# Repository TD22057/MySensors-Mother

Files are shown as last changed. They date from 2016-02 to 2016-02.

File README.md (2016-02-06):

# MySensors Mother/Daughter board system

This repository contains the PCB design files, 3D renderings, and
software libraries to implement the
[MySensors](http:www.mysensors.org) mother/daughter board system
[described in this
thread](http://forum.mysensors.org/topic/2480/mother-daughter-board-system).

It's a mother/daughter board design using an RFM69 radio (though it
would be easy to change it to an NRF). I have about 10 sensors I need
to make and they're all similar, but not quite the same. This system
allows be to mix and match what I need for each application. It's
designed to be AC powered and uses a single case (see below) for all
of them (~$3/apiece for 10).

The main board has the basic components and supports two daughter
boards (roughly 25mm x 35mm) which plug into the side so the whole
assembly is basically flat (leaving more room in the case for the
switches, connectors, and LED's). An additional third daughter board
can be used for small boards mounted perpendicular to the main boards
(the sensor board below does that) or mounting over the top of the
arduino.

The main board contains:

- 3.3V Arduino Pro Mini
- RFM69 radio
   - side mount for external dipole antenna
   - interior mount with enough space for a helical antenna mounted
     parallel or perpendicular to the board
- 5V->3.3V power supply
- digital signing chip
- flash memory chip
- input and output shift registers
- headers for a switch, LED, and piezo buzzer
- header for SPI (MISO, MOSI, SCK) pins
- 2 side mounted daughter board headers with inputs and outputs from
  the shift registers
- 1 top mounted daughter board header with pins from the mini including
  D3 (IRQ), D5 and D6 (PWM), A3, A4 (SDA), and A5 (SCL)
- all components are top mounted for easier soldering and a bigger
  ground plane for better antenna performance

# Boards

Each daughter board header has 5V, 3.3V, ground, 3 input pins, and 3
output pins.  I've designed seven different daughter boards so far.   

- Valve/motor control board. I'm using this for articulated water
  valves for controlling leaks at the water heater, washing machine,
  etc.  It contains a L9110 motor controller, LED, and valve
  open/closed sensors.
- AC relay board. I'm using this to control simple AC load switching
  (in my case, a recirculation pump).  The board contains an
  opto-isolated AC relay with NO and NC terminals, 1 LED, and 2 sensor
  inputs with pull down resistors.
- DC relay board. I'm using this to control simple DC load switching
  (in my case, a triggering a garage door).  The board contains an
  opto-isolated DC relay with NO and NC terminals, 2 LED's, and 3 sensor
  inputs with pull down resistors.
- Protected input board. I'm using this to trigger when external
  security cameras and motion sensors trip (they both operate on 12V
  signals).  The board contains 3 opto-isolator circuits for
  triggering on 12V lines.
- Parking/RGB sensor board.  This board contains pins for an
  ultrasonic distance sensor and an RGB (neopixel) ring.  It includes
  5V/3.3V level shifting for the distance sensor.  This board must be
  connected to the 3'rd slot which interfaces directly with the
  Arduino pins because of the neopixel timing requirements.
- Sensor board.  3 sensor inputs with pull down resistors and 3 LED
  outputs with 1K resistors.  This is designed primarily for water
  leak detectors.  The rope leak sensor I'm using works better w/ 5V
  input and analog output so sensors can be fed with 5V or 3.3V and
  when connected in the 3'rd slot, they will output to the Arduino's
  analog pins.
- I2C board.  This is simple small board that adds multiple I2C pins.

Here's an image of the assembled boards:

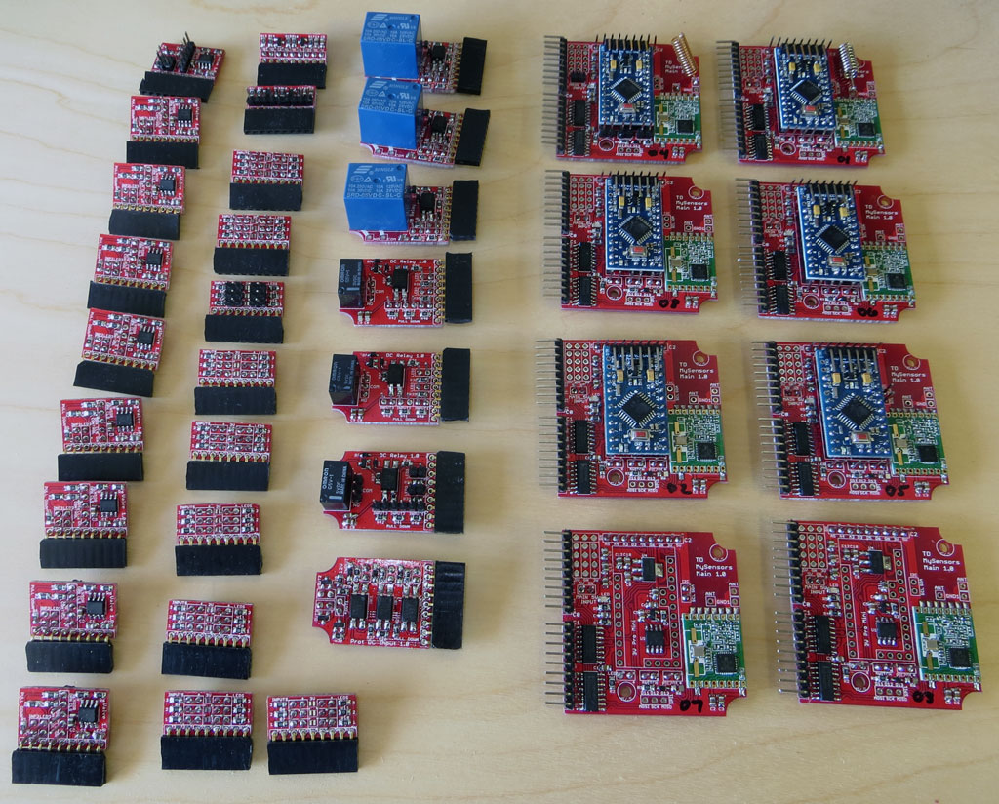
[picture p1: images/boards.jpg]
Boards


# Ordering

The boards file contains the individual board designs (done in Eagle)
as well as panelized versions.  A single 10cm x 10cm panel contains 2
main boards, 1 each of the AC relay, DC relay, protected input,
parking board, and I2C board; 2 valve boards; and 3 sensor boards.  

# Project Case

The boards are designed to fit inside a specific case (size and
mounting holes) which can be [found
here](http://www.aliexpress.com/item/Wholesale-electrical-junction-box-10pcs-105-65-40mm-plastic-instrument-box-plastic-box-electronic-project-box/1986580384.html).
There are many options for ordering this case on AliExpress (various
quantities and vendors).  Searching for ["105\*65\*40mm"](http://www.aliexpress.com/af/105*65*40mm.html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) will
generally show them all.

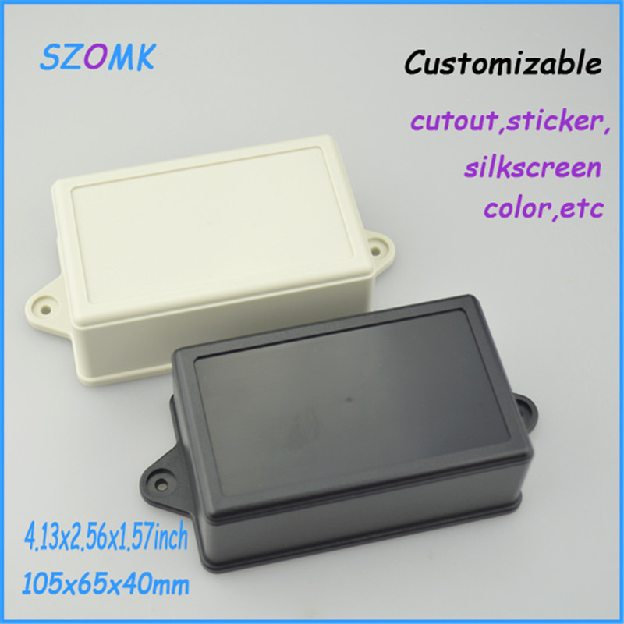
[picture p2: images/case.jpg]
Case


# Software

The lib directory contains a class for each board.  Each child board
class is constructed by passing it a structure from the main board
class which defines which slot it's plugged in to.  The boards (mother
and children) all contain elements for manipulating their components
(LED's, relays, sensors, etc) which abstract away the method by which
their connected (call sensor.led[0].on() to turn on the 0'th LED of a
sensor board) which makes writing the final sketches which use the
boards very easy.

The software does depend on my [arduino-core library
classes](https://github.com/TD22057/TD-Arduino-Core).

# Licenses

All the software in this repository is covered by the GPL-V3 license
(see [LICENSE-software](LICENSE-software)).

All the hardare in this repository is covered by the CERN Open
Hardware Licence v1.2 (see [LICENSE-hardware](LICENSE-hardware)).

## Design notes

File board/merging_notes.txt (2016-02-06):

To created merged board:

Use eagle-brd-merge python script (https://github.com/p12tic/eagle-brd-merge)
Command:
merge.py merge.brd Mother\ v1.0\ -\ panel.brd Child\ v1.0\ -\ panel1.brd --offx .83375mm --offy 50mm

moves child board up 50mm and right a small amount to line up w/ main board cutouts.

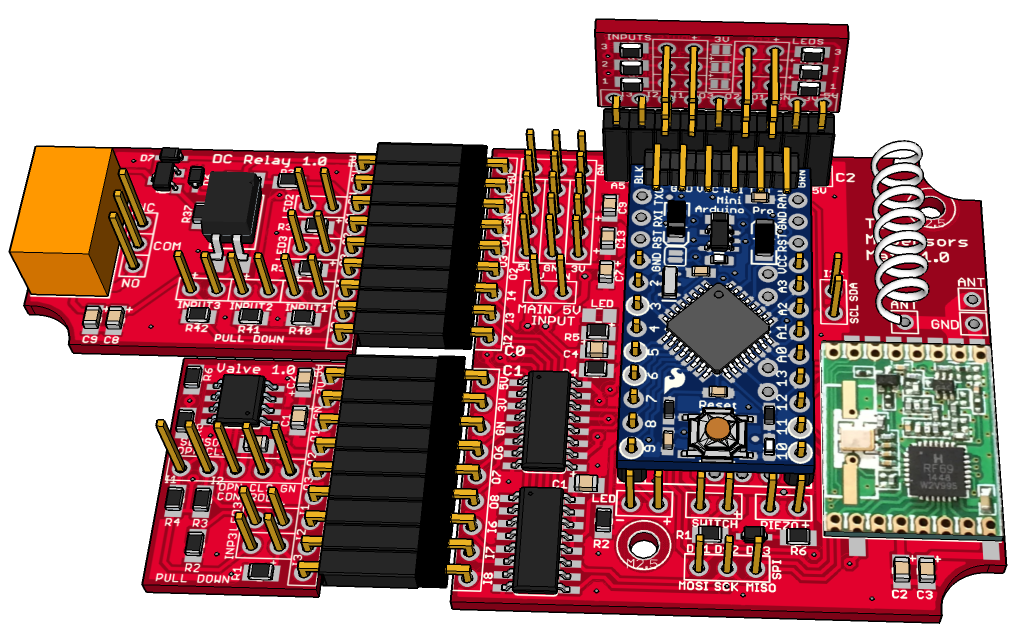
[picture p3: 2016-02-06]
images/main.png

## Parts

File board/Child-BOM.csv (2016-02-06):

Part | Value | Device | Package | Description | Link
C1 | 0.1uF | Capacitor X7R 50V | 805 |  | http://www.aliexpress.com/item/SMD-0805-0-1UF-50V-capacitor-100NF-104K-X7R-10-100pcs/32330657462.html
C2 | 10uF | Capacitor X7R 50V | 805 |  | http://www.aliexpress.com/item/Free-shipping-0805-10UF-50V-106K-10-X7R-100pcs/32333829597.html
C3 | 0.1uF | Capacitor X7R 50V | 805 |  | http://www.aliexpress.com/item/SMD-0805-0-1UF-50V-capacitor-100NF-104K-X7R-10-100pcs/32330657462.html
C4 | 10uF | Capacitor X7R 50V | 805 |  | http://www.aliexpress.com/item/Free-shipping-0805-10UF-50V-106K-10-X7R-100pcs/32333829597.html
C5 | 0.1uF | Capacitor X7R 50V | 805 |  | http://www.aliexpress.com/item/SMD-0805-0-1UF-50V-capacitor-100NF-104K-X7R-10-100pcs/32330657462.html
C6 | 10uF | Capacitor X7R 50V | 805 |  | http://www.aliexpress.com/item/Free-shipping-0805-10UF-50V-106K-10-X7R-100pcs/32333829597.html
C7 | 0.1uF | Capacitor X7R 50V | 805 |  | http://www.aliexpress.com/item/SMD-0805-0-1UF-50V-capacitor-100NF-104K-X7R-10-100pcs/32330657462.html
C8 | 10uF | Capacitor X7R 50V | 805 |  | http://www.aliexpress.com/item/Free-shipping-0805-10UF-50V-106K-10-X7R-100pcs/32333829597.html
C9 | 0.1uF | Capacitor X7R 50V | 805 |  | http://www.aliexpress.com/item/SMD-0805-0-1UF-50V-capacitor-100NF-104K-X7R-10-100pcs/32330657462.html
D1 |  | 1N4148 Diode | SOD323 |  | http://www.aliexpress.com/item/Free-shipping-100PCS-1N4148-SMD-IN4148-0805-SOD-323-Switching-Diode/1578916085.html
D2 |  | 1N4148 Diode | SOD323 |  | http://www.aliexpress.com/item/Free-shipping-100PCS-1N4148-SMD-IN4148-0805-SOD-323-Switching-Diode/1578916085.html
D3 |  | 1N4148 Diode | SOD323 |  | http://www.aliexpress.com/item/Free-shipping-100PCS-1N4148-SMD-IN4148-0805-SOD-323-Switching-Diode/1578916085.html
D4 |  | 1N4148 Diode | SOD323 |  | http://www.aliexpress.com/item/Free-shipping-100PCS-1N4148-SMD-IN4148-0805-SOD-323-Switching-Diode/1578916085.html
D5 |  | 1N4148 Diode | SOD323 |  | http://www.aliexpress.com/item/Free-shipping-100PCS-1N4148-SMD-IN4148-0805-SOD-323-Switching-Diode/1578916085.html
D6 |  | 1N4148 Diode | SOD323 |  | http://www.aliexpress.com/item/Free-shipping-100PCS-1N4148-SMD-IN4148-0805-SOD-323-Switching-Diode/1578916085.html
D7 |  | 1N4148 Diode | SOD323 |  | http://www.aliexpress.com/item/Free-shipping-100PCS-1N4148-SMD-IN4148-0805-SOD-323-Switching-Diode/1578916085.html
L1 |  | BSS138 Mosfet | SOT23-3 | Logic Level converter 5V->3.3V | http://www.aliexpress.com/item/100pcs-lot-DIN7985-M2-5-5mm-Stainless-Steel-A2-Pan-Head-Phillips-Cross-recessed-pan-head/940264374.html
L2 |  | BSS138 Mosfet | SOT23-3 | Logic Level converter 5V->3.3V | http://www.aliexpress.com/item/100pcs-lot-DIN7985-M2-5-5mm-Stainless-Steel-A2-Pan-Head-Phillips-Cross-recessed-pan-head/940264374.html
L9110 |  | L9110 motor driver | SO-08 |  | http://www.aliexpress.com/item/10PCS-free-shipping-100-new-original-patch-of-L9110S-full-bridge-driver-motor-drive-chip-new/1692421710.html
OK1 |  | PC817 optocoupler | SO-4 |  | http://www.aliexpress.com/item/Free-shipping-New-original-Everlight-SMD-optocoupler-EL817C-PC817-EL817S-C-SOP-4-guaranteed-authentic/1911433513.html
OK2 |  | PC817 optocoupler | SO-4 |  | http://www.aliexpress.com/item/Free-shipping-New-original-Everlight-SMD-optocoupler-EL817C-PC817-EL817S-C-SOP-4-guaranteed-authentic/1911433513.html
OK3 |  | PC817 optocoupler | SO-4 |  | http://www.aliexpress.com/item/Free-shipping-New-original-Everlight-SMD-optocoupler-EL817C-PC817-EL817S-C-SOP-4-guaranteed-authentic/1911433513.html
PINP1 |  | 2 pin, male pins |  |  | http://www.aliexpress.com/item/10pcs-Connector-2-54mm-40-Pin-Male-Single-Row-silver-Pin-Header-Strip-Brand-New/32417455102.html
PINP2 |  | 2 pin, male pins |  |  | http://www.aliexpress.com/item/10pcs-Connector-2-54mm-40-Pin-Male-Single-Row-silver-Pin-Header-Strip-Brand-New/32417455102.html
PINP3 |  | 2 pin, male pins |  |  | http://www.aliexpress.com/item/10pcs-Connector-2-54mm-40-Pin-Male-Single-Row-silver-Pin-Header-Strip-Brand-New/32417455102.html
PRK_DIST |  | 4 pin, male pins |  |  | http://www.aliexpress.com/item/10pcs-Connector-2-54mm-40-Pin-Male-Single-Row-silver-Pin-Header-Strip-Brand-New/32417455102.html
PRK_LED |  | 3 pin, male pins |  |  | http://www.aliexpress.com/item/10pcs-Connector-2-54mm-40-Pin-Male-Single-Row-silver-Pin-Header-Strip-Brand-New/32417455102.html
PSWITCH |  | 2 pin, male pins |  |  | http://www.aliexpress.com/item/10pcs-Connector-2-54mm-40-Pin-Male-Single-Row-silver-Pin-Header-Strip-Brand-New/32417455102.html
R1 | 10K | Resistor | 805 |  | http://www.aliexpress.com/item/0805-SMD-Resistors-10k-10K-ohm-1-8W-5-0805-SMD-Resistors-0805-Chip-resistor-500pcs/852348196.html
R2 | 1K | Resistor | 805 |  | http://www.aliexpress.com/item/0805-SMD-Resistors-1k-1K-ohm-1-8W-5-0805-SMD-Resistors-0805-Chip-resistor-500pcs/852303271.html
R2_LED |  | 2 pin, male pins |  |  | http://www.aliexpress.com/item/10pcs-Connector-2-54mm-40-Pin-Male-Single-Row-silver-Pin-Header-Strip-Brand-New/32417455102.html
R2_OC1 |  | PC817 optocoupler | SO-4 |  | http://www.aliexpress.com/item/Free-shipping-New-original-Everlight-SMD-optocoupler-EL817C-PC817-EL817S-C-SOP-4-guaranteed-authentic/1911433513.html
R2_RELAY |  | 5V 10A relay |  |  | http://www.aliexpress.com/item/Free-Shipping-10PCS-SRD-5VDC-SL-C-PCB-Type-5V-DC/662939016.html
R2_SW |  | 2 pin, male pins |  |  | http://www.aliexpress.com/item/10pcs-Connector-2-54mm-40-Pin-Male-Single-Row-silver-Pin-Header-Strip-Brand-New/32417455102.html
R2_SW1 |  | 2 pin, male pins |  |  | http://www.aliexpress.com/item/10pcs-Connector-2-54mm-40-Pin-Male-Single-Row-silver-Pin-Header-Strip-Brand-New/32417455102.html
R3 | 10K | Resistor | 805 |  | http://www.aliexpress.com/item/0805-SMD-Resistors-10k-10K-ohm-1-8W-5-0805-SMD-Resistors-0805-Chip-resistor-500pcs/852348196.html
R3_LED |  | 2 pin, male pins |  |  | http://www.aliexpress.com/item/10pcs-Connector-2-54mm-40-Pin-Male-Single-Row-silver-Pin-Header-Strip-Brand-New/32417455102.html
R3_LED1 |  | 2 pin, male pins |  |  | http://www.aliexpress.com/item/10pcs-Connector-2-54mm-40-Pin-Male-Single-Row-silver-Pin-Header-Strip-Brand-New/32417455102.html
R3_OC |  | PC817 optocoupler | SO-4 |  | http://www.aliexpress.com/item/Free-shipping-New-original-Everlight-SMD-optocoupler-EL817C-PC817-EL817S-C-SOP-4-guaranteed-authentic/1911433513.html
R4 | 10K | Resistor | 805 |  | http://www.aliexpress.com/item/0805-SMD-Resistors-10k-10K-ohm-1-8W-5-0805-SMD-Resistors-0805-Chip-resistor-500pcs/852348196.html
R5 | 10K | Resistor | 805 |  | http://www.aliexpress.com/item/0805-SMD-Resistors-10k-10K-ohm-1-8W-5-0805-SMD-Resistors-0805-Chip-resistor-500pcs/852348196.html
R6 | 10K | Resistor | 805 |  | http://www.aliexpress.com/item/0805-SMD-Resistors-10k-10K-ohm-1-8W-5-0805-SMD-Resistors-0805-Chip-resistor-500pcs/852348196.html
R7 | 10K | Resistor | 805 |  | http://www.aliexpress.com/item/0805-SMD-Resistors-10k-10K-ohm-1-8W-5-0805-SMD-Resistors-0805-Chip-resistor-500pcs/852348196.html
R8 | 10K | Resistor | 805 |  | http://www.aliexpress.com/item/0805-SMD-Resistors-10k-10K-ohm-1-8W-5-0805-SMD-Resistors-0805-Chip-resistor-500pcs/852348196.html
R9 | 10K | Resistor | 805 |  | http://www.aliexpress.com/item/0805-SMD-Resistors-10k-10K-ohm-1-8W-5-0805-SMD-Resistors-0805-Chip-resistor-500pcs/852348196.html
R10 | 1K | Resistor | 805 |  | http://www.aliexpress.com/item/0805-SMD-Resistors-1k-1K-ohm-1-8W-5-0805-SMD-Resistors-0805-Chip-resistor-500pcs/852303271.html
R11 | 1K | Resistor | 805 |  | http://www.aliexpress.com/item/0805-SMD-Resistors-1k-1K-ohm-1-8W-5-0805-SMD-Resistors-0805-Chip-resistor-500pcs/852303271.html
R12 | 1K | Resistor | 805 |  | http://www.aliexpress.com/item/0805-SMD-Resistors-1k-1K-ohm-1-8W-5-0805-SMD-Resistors-0805-Chip-resistor-500pcs/852303271.html
R13 | 10K | Resistor | 805 |  | http://www.aliexpress.com/item/0805-SMD-Resistors-10k-10K-ohm-1-8W-5-0805-SMD-Resistors-0805-Chip-resistor-500pcs/852348196.html
R14 | 10K | Resistor | 805 |  | http://www.aliexpress.com/item/0805-SMD-Resistors-10k-10K-ohm-1-8W-5-0805-SMD-Resistors-0805-Chip-resistor-500pcs/852348196.html
R15 | 10K | Resistor | 805 |  | http://www.aliexpress.com/item/0805-SMD-Resistors-10k-10K-ohm-1-8W-5-0805-SMD-Resistors-0805-Chip-resistor-500pcs/852348196.html
R16 | 10K | Resistor | 805 |  | http://www.aliexpress.com/item/0805-SMD-Resistors-10k-10K-ohm-1-8W-5-0805-SMD-Resistors-0805-Chip-resistor-500pcs/852348196.html
R17 | 10K | Resistor | 805 |  | http://www.aliexpress.com/item/0805-SMD-Resistors-10k-10K-ohm-1-8W-5-0805-SMD-Resistors-0805-Chip-resistor-500pcs/852348196.html
R18 | 4K7 | Resistor | 805 |  | http://www.aliexpress.com/item/0805-SMD-Resistors-4K7-4-7K-ohm-1-8W-5-0805-SMD-Resistors-0805-Chip-resistor/852419496.html
R19 | 4K7 | Resistor | 805 |  | http://www.aliexpress.com/item/0805-SMD-Resistors-4K7-4-7K-ohm-1-8W-5-0805-SMD-Resistors-0805-Chip-resistor/852419496.html
R20 | 10K | Resistor | 805 |  | http://www.aliexpress.com/item/0805-SMD-Resistors-10k-10K-ohm-1-8W-5-0805-SMD-Resistors-0805-Chip-resistor-500pcs/852348196.html
R21 | 10K | Resistor | 805 |  | http://www.aliexpress.com/item/0805-SMD-Resistors-10k-10K-ohm-1-8W-5-0805-SMD-Resistors-0805-Chip-resistor-500pcs/852348196.html
R22 | 4.7K | Resistor | 805 |  | http://www.aliexpress.com/item/0805-SMD-Resistors-4K7-4-7K-ohm-1-8W-5-0805-SMD-Resistors-0805-Chip-resistor/852419496.html
R23 | 4.7K | Resistor | 805 |  | http://www.aliexpress.com/item/0805-SMD-Resistors-4K7-4-7K-ohm-1-8W-5-0805-SMD-Resistors-0805-Chip-resistor/852419496.html
R24 | 4.7K | Resistor | 805 |  | http://www.aliexpress.com/item/0805-SMD-Resistors-4K7-4-7K-ohm-1-8W-5-0805-SMD-Resistors-0805-Chip-resistor/852419496.html
R25 | 10K | Resistor | 805 |  | http://www.aliexpress.com/item/0805-SMD-Resistors-10k-10K-ohm-1-8W-5-0805-SMD-Resistors-0805-Chip-resistor-500pcs/852348196.html
R26 | 10K | Resistor | 805 |  | http://www.aliexpress.com/item/0805-SMD-Resistors-10k-10K-ohm-1-8W-5-0805-SMD-Resistors-0805-Chip-resistor-500pcs/852348196.html
R27 | 10K | Resistor | 805 |  | http://www.aliexpress.com/item/0805-SMD-Resistors-10k-10K-ohm-1-8W-5-0805-SMD-Resistors-0805-Chip-resistor-500pcs/852348196.html
R28 | 1K | Resistor | 805 |  | http://www.aliexpress.com/item/0805-SMD-Resistors-1k-1K-ohm-1-8W-5-0805-SMD-Resistors-0805-Chip-resistor-500pcs/852303271.html
R29 | 1K | Resistor | 805 |  | http://www.aliexpress.com/item/0805-SMD-Resistors-1k-1K-ohm-1-8W-5-0805-SMD-Resistors-0805-Chip-resistor-500pcs/852303271.html
R30 | 1K | Resistor | 805 |  | http://www.aliexpress.com/item/0805-SMD-Resistors-1k-1K-ohm-1-8W-5-0805-SMD-Resistors-0805-Chip-resistor-500pcs/852303271.html
R31 | 1K | Resistor | 805 |  | http://www.aliexpress.com/item/0805-SMD-Resistors-1k-1K-ohm-1-8W-5-0805-SMD-Resistors-0805-Chip-resistor-500pcs/852303271.html
R32 | 1K | Resistor | 805 |  | http://www.aliexpress.com/item/0805-SMD-Resistors-1k-1K-ohm-1-8W-5-0805-SMD-Resistors-0805-Chip-resistor-500pcs/852303271.html
R33 | 10K | Resistor | 805 |  | http://www.aliexpress.com/item/0805-SMD-Resistors-10k-10K-ohm-1-8W-5-0805-SMD-Resistors-0805-Chip-resistor-500pcs/852348196.html
R34 | 1K | Resistor | 805 |  | http://www.aliexpress.com/item/0805-SMD-Resistors-1k-1K-ohm-1-8W-5-0805-SMD-Resistors-0805-Chip-resistor-500pcs/852303271.html
R35 | 10K | Resistor | 805 |  | http://www.aliexpress.com/item/0805-SMD-Resistors-10k-10K-ohm-1-8W-5-0805-SMD-Resistors-0805-Chip-resistor-500pcs/852348196.html
R36 | 1K | Resistor | 805 |  | http://www.aliexpress.com/item/0805-SMD-Resistors-1k-1K-ohm-1-8W-5-0805-SMD-Resistors-0805-Chip-resistor-500pcs/852303271.html
R37 | 1K | Resistor | 805 |  | http://www.aliexpress.com/item/0805-SMD-Resistors-1k-1K-ohm-1-8W-5-0805-SMD-Resistors-0805-Chip-resistor-500pcs/852303271.html
R38 | 1K | Resistor | 805 |  | http://www.aliexpress.com/item/0805-SMD-Resistors-1k-1K-ohm-1-8W-5-0805-SMD-Resistors-0805-Chip-resistor-500pcs/852303271.html
R39 | 1K | Resistor | 805 |  | http://www.aliexpress.com/item/0805-SMD-Resistors-1k-1K-ohm-1-8W-5-0805-SMD-Resistors-0805-Chip-resistor-500pcs/852303271.html
R40 | 10K | Resistor | 805 |  | http://www.aliexpress.com/item/0805-SMD-Resistors-10k-10K-ohm-1-8W-5-0805-SMD-Resistors-0805-Chip-resistor-500pcs/852348196.html
R41 | 10K | Resistor | 805 |  | http://www.aliexpress.com/item/0805-SMD-Resistors-10k-10K-ohm-1-8W-5-0805-SMD-Resistors-0805-Chip-resistor-500pcs/852348196.html
R42 | 10K | Resistor | 805 |  | http://www.aliexpress.com/item/0805-SMD-Resistors-10k-10K-ohm-1-8W-5-0805-SMD-Resistors-0805-Chip-resistor-500pcs/852348196.html
RELAY4 |  | 2 pin, male pins |  |  | http://www.aliexpress.com/item/10pcs-Connector-2-54mm-40-Pin-Male-Single-Row-silver-Pin-Header-Strip-Brand-New/32417455102.html
RELAY5 |  | 2 pin, male pins |  |  | http://www.aliexpress.com/item/10pcs-Connector-2-54mm-40-Pin-Male-Single-Row-silver-Pin-Header-Strip-Brand-New/32417455102.html
RELAY6 |  | 2 pin, male pins |  |  | http://www.aliexpress.com/item/10pcs-Connector-2-54mm-40-Pin-Male-Single-Row-silver-Pin-Header-Strip-Brand-New/32417455102.html
RINP4 |  | 2 pin, male pins |  |  | http://www.aliexpress.com/item/10pcs-Connector-2-54mm-40-Pin-Male-Single-Row-silver-Pin-Header-Strip-Brand-New/32417455102.html
RINP5 |  | 2 pin, male pins |  |  | http://www.aliexpress.com/item/10pcs-Connector-2-54mm-40-Pin-Male-Single-Row-silver-Pin-Header-Strip-Brand-New/32417455102.html
RINP6 |  | 2 pin, male pins |  |  | http://www.aliexpress.com/item/10pcs-Connector-2-54mm-40-Pin-Male-Single-Row-silver-Pin-Header-Strip-Brand-New/32417455102.html
SENLED1 |  | 2 pin, male pins |  |  | http://www.aliexpress.com/item/10pcs-Connector-2-54mm-40-Pin-Male-Single-Row-silver-Pin-Header-Strip-Brand-New/32417455102.html
SENLED2 |  | 2 pin, male pins |  |  | http://www.aliexpress.com/item/10pcs-Connector-2-54mm-40-Pin-Male-Single-Row-silver-Pin-Header-Strip-Brand-New/32417455102.html
SENLED3 |  | 2 pin, male pins |  |  | http://www.aliexpress.com/item/10pcs-Connector-2-54mm-40-Pin-Male-Single-Row-silver-Pin-Header-Strip-Brand-New/32417455102.html
SENSOR1 |  | 2 pin, male pins |  |  | http://www.aliexpress.com/item/10pcs-Connector-2-54mm-40-Pin-Male-Single-Row-silver-Pin-Header-Strip-Brand-New/32417455102.html
SENSOR2 |  | 2 pin, male pins |  |  | http://www.aliexpress.com/item/10pcs-Connector-2-54mm-40-Pin-Male-Single-Row-silver-Pin-Header-Strip-Brand-New/32417455102.html
SENSOR3 |  | 2 pin, male pins |  |  | http://www.aliexpress.com/item/10pcs-Connector-2-54mm-40-Pin-Male-Single-Row-silver-Pin-Header-Strip-Brand-New/32417455102.html
SENSOR4 |  | 2 pin, male pins |  |  | http://www.aliexpress.com/item/10pcs-Connector-2-54mm-40-Pin-Male-Single-Row-silver-Pin-Header-Strip-Brand-New/32417455102.html
SENSOR5 |  | 2 pin, male pins |  |  | http://www.aliexpress.com/item/10pcs-Connector-2-54mm-40-Pin-Male-Single-Row-silver-Pin-Header-Strip-Brand-New/32417455102.html
SENSOR7 |  | 2 pin, male pins |  |  | http://www.aliexpress.com/item/10pcs-Connector-2-54mm-40-Pin-Male-Single-Row-silver-Pin-Header-Strip-Brand-New/32417455102.html
SENSOR8 |  | 2 pin, male pins |  |  | http://www.aliexpress.com/item/10pcs-Connector-2-54mm-40-Pin-Male-Single-Row-silver-Pin-Header-Strip-Brand-New/32417455102.html
U$1 |  | 9 pin, female, 90 deg header |  |  | http://www.aliexpress.com/item/10pcs-1x40-Pin-2-54mm-Right-Angle-Single-Row-Female-Pin-Header-Connector/32412624930.html
U$2 |  | 9 pin, female, 90 deg header |  |  | http://www.aliexpress.com/item/10pcs-1x40-Pin-2-54mm-Right-Angle-Single-Row-Female-Pin-Header-Connector/32412624930.html
U$3 |  | G5V 5V relay |  |  | http://www.aliexpress.com/item/G5V-1-5V-g5v-1-5-G5V-1-5VDC-5pcs-lot/32380269321.html
U$4 |  | 9 pin, female, 90 deg header |  |  | http://www.aliexpress.com/item/10pcs-1x40-Pin-2-54mm-Right-Angle-Single-Row-Female-Pin-Header-Connector/32412624930.html
U$6 |  | 9 pin, female, 90 deg header |  |  | http://www.aliexpress.com/item/10pcs-1x40-Pin-2-54mm-Right-Angle-Single-Row-Female-Pin-Header-Connector/32412624930.html
U$7 |  | 9 pin, female, 90 deg header |  |  | http://www.aliexpress.com/item/10pcs-1x40-Pin-2-54mm-Right-Angle-Single-Row-Female-Pin-Header-Connector/32412624930.html
U$8 |  | 2N2222 Transistor | SOT23-3 |  | http://www.aliexpress.com/item/MMBT2222A-patch-Transistor-2N2222-SMD-1P-printing-package-SOT23-NPN-KBSM/32469039785.html
U$9 |  | 1 pin, male pins |  |  | http://www.aliexpress.com/item/10pcs-Connector-2-54mm-40-Pin-Male-Single-Row-silver-Pin-Header-Strip-Brand-New/32417455102.html
U$10 |  | 1 pin, male pins |  |  | http://www.aliexpress.com/item/10pcs-Connector-2-54mm-40-Pin-Male-Single-Row-silver-Pin-Header-Strip-Brand-New/32417455102.html
U$11 |  | 1 pin, male pins |  |  | http://www.aliexpress.com/item/10pcs-Connector-2-54mm-40-Pin-Male-Single-Row-silver-Pin-Header-Strip-Brand-New/32417455102.html
U$12 |  | 1 pin, male pins |  |  | http://www.aliexpress.com/item/10pcs-Connector-2-54mm-40-Pin-Male-Single-Row-silver-Pin-Header-Strip-Brand-New/32417455102.html
U$13 |  | 2N2222 Transistor | SOT23-3
U$14 |  | 9 pin, female, 90 deg header |  |  | http://www.aliexpress.com/item/10pcs-1x40-Pin-2-54mm-Right-Angle-Single-Row-Female-Pin-Header-Connector/32412624930.html
U$15 |  | 1 pin, male pins |  |  | http://www.aliexpress.com/item/10pcs-Connector-2-54mm-40-Pin-Male-Single-Row-silver-Pin-Header-Strip-Brand-New/32417455102.html
U$16 |  | 1 pin, male pins |  |  | http://www.aliexpress.com/item/10pcs-Connector-2-54mm-40-Pin-Male-Single-Row-silver-Pin-Header-Strip-Brand-New/32417455102.html
U$17 |  | 1 pin, male pins |  |  | http://www.aliexpress.com/item/10pcs-Connector-2-54mm-40-Pin-Male-Single-Row-silver-Pin-Header-Strip-Brand-New/32417455102.html
U$18 |  | 9 pin, female, 90 deg header |  |  | http://www.aliexpress.com/item/10pcs-1x40-Pin-2-54mm-Right-Angle-Single-Row-Female-Pin-Header-Connector/32412624930.html
U$19 |  | 1 pin, male pins |  |  | http://www.aliexpress.com/item/10pcs-Connector-2-54mm-40-Pin-Male-Single-Row-silver-Pin-Header-Strip-Brand-New/32417455102.html
U$20 |  | 1 pin, male pins |  |  | http://www.aliexpress.com/item/10pcs-Connector-2-54mm-40-Pin-Male-Single-Row-silver-Pin-Header-Strip-Brand-New/32417455102.html
U$21 |  | 1 pin, male pins |  |  | http://www.aliexpress.com/item/10pcs-Connector-2-54mm-40-Pin-Male-Single-Row-silver-Pin-Header-Strip-Brand-New/32417455102.html
U$22 |  | 1 pin, male pins |  |  | http://www.aliexpress.com/item/10pcs-Connector-2-54mm-40-Pin-Male-Single-Row-silver-Pin-Header-Strip-Brand-New/32417455102.html
U$23 |  | 3 pin, male pins |  |  | http://www.aliexpress.com/item/10pcs-Connector-2-54mm-40-Pin-Male-Single-Row-silver-Pin-Header-Strip-Brand-New/32417455102.html
U$24 |  | 3 pin, male pins |  |  | http://www.aliexpress.com/item/10pcs-Connector-2-54mm-40-Pin-Male-Single-Row-silver-Pin-Header-Strip-Brand-New/32417455102.html
U2 |  | 2N2222 Transistor | SOT23-3 |  | http://www.aliexpress.com/item/MMBT2222A-patch-Transistor-2N2222-SMD-1P-printing-package-SOT23-NPN-KBSM/32469039785.html
U5 |  | 2N2222 Transistor | SOT23-3 |  | http://www.aliexpress.com/item/MMBT2222A-patch-Transistor-2N2222-SMD-1P-printing-package-SOT23-NPN-KBSM/32469039785.html
U6 |  | 2N2222 Transistor | SOT23-3 |  | http://www.aliexpress.com/item/MMBT2222A-patch-Transistor-2N2222-SMD-1P-printing-package-SOT23-NPN-KBSM/32469039785.html
VALVE |  | 5 pin, male pins |  |  | http://www.aliexpress.com/item/10pcs-Connector-2-54mm-40-Pin-Male-Single-Row-silver-Pin-Header-Strip-Brand-New/32417455102.html
VLV_LED |  | 2 pin, male pins |  |  | http://www.aliexpress.com/item/10pcs-Connector-2-54mm-40-Pin-Male-Single-Row-silver-Pin-Header-Strip-Brand-New/32417455102.html

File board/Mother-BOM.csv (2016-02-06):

Part | Value | Device | Package | Description | Link
C1 | 0.1uF | Capacitor X7R 50V | 805 |  | http://www.aliexpress.com/item/SMD-0805-0-1UF-50V-capacitor-100NF-104K-X7R-10-100pcs/32330657462.html
C2 | 10uF | Capacitor X7R 50V | 805 |  | http://www.aliexpress.com/item/Free-shipping-0805-10UF-50V-106K-10-X7R-100pcs/32333829597.html
C3 | 0.1uF | Capacitor X7R 50V | 805 |  | http://www.aliexpress.com/item/SMD-0805-0-1UF-50V-capacitor-100NF-104K-X7R-10-100pcs/32330657462.html
C4 | 0.1uF | Capacitor X7R 50V | 805 |  | http://www.aliexpress.com/item/SMD-0805-0-1UF-50V-capacitor-100NF-104K-X7R-10-100pcs/32330657462.html
C5 | 0.1uF | Capacitor X7R 50V | 805 |  | http://www.aliexpress.com/item/SMD-0805-0-1UF-50V-capacitor-100NF-104K-X7R-10-100pcs/32330657462.html
C6 | 0.1uF | Capacitor X7R 50V | 805 |  | http://www.aliexpress.com/item/SMD-0805-0-1UF-50V-capacitor-100NF-104K-X7R-10-100pcs/32330657462.html
C7 | 10uF | Capacitor X7R 50V | 805 |  | http://www.aliexpress.com/item/Free-shipping-0805-10UF-50V-106K-10-X7R-100pcs/32333829597.html
C8 | 0.1uF | Capacitor X7R 50V | 805 |  | http://www.aliexpress.com/item/SMD-0805-0-1UF-50V-capacitor-100NF-104K-X7R-10-100pcs/32330657462.html
C9 | 10uF | Capacitor X7R 50V | 805 |  | http://www.aliexpress.com/item/Free-shipping-0805-10UF-50V-106K-10-X7R-100pcs/32333829597.html
C10 | 0.1uF | Capacitor X7R 50V | 805 |  | http://www.aliexpress.com/item/SMD-0805-0-1UF-50V-capacitor-100NF-104K-X7R-10-100pcs/32330657462.html
C11 | 10uF | Capacitor X7R 50V | 805 |  | http://www.aliexpress.com/item/Free-shipping-0805-10UF-50V-106K-10-X7R-100pcs/32333829597.html
C12 | 10uF | Capacitor X7R 50V | 805 |  | http://www.aliexpress.com/item/Free-shipping-0805-10UF-50V-106K-10-X7R-100pcs/32333829597.html
C13 | 10uF | Capacitor X7R 50V | 805 |  | http://www.aliexpress.com/item/Free-shipping-0805-10UF-50V-106K-10-X7R-100pcs/32333829597.html
D1 |  | 1N4148 Diode | SOD323 |  | http://www.aliexpress.com/item/Free-shipping-100PCS-1N4148-SMD-IN4148-0805-SOD-323-Switching-Diode/1578916085.html
H1 |  | M2.5 mounting hole |  |  | http://www.aliexpress.com/item/100pcs-lot-DIN7985-M2-5-5mm-Stainless-Steel-A2-Pan-Head-Phillips-Cross-recessed-pan-head/940264374.html
H2 |  | M2.5 mounting hole |  |  | http://www.aliexpress.com/item/100pcs-lot-DIN7985-M2-5-5mm-Stainless-Steel-A2-Pan-Head-Phillips-Cross-recessed-pan-head/940264374.html
I2C |  | 2 pin, male pins |  |  | http://www.aliexpress.com/item/10pcs-Connector-2-54mm-40-Pin-Male-Single-Row-silver-Pin-Header-Strip-Brand-New/32417455102.html
IC_IN |  | MM74HC589 | SO16 | Input shift register with SPI support | https://www.digikey.com/product-detail/en/MC74HC589ADG/MC74HC589ADGOS-ND/1480105
IC_OUT |  | 74HC595 | SO16 | Output shift register | http://www.aliexpress.com/item/Free-shipping-50pcs-74HC595D-74HC595-SOP16/910702058.html
J3V1 |  | 4 pin, male pins |  |  | http://www.aliexpress.com/item/10pcs-Connector-2-54mm-40-Pin-Male-Single-Row-silver-Pin-Header-Strip-Brand-New/32417455102.html
J5V |  | 4 pin, male pins |  |  | http://www.aliexpress.com/item/10pcs-Connector-2-54mm-40-Pin-Male-Single-Row-silver-Pin-Header-Strip-Brand-New/32417455102.html
JGN1 |  | 4 pin, male pins |  |  | http://www.aliexpress.com/item/10pcs-Connector-2-54mm-40-Pin-Male-Single-Row-silver-Pin-Header-Strip-Brand-New/32417455102.html
JGN2 |  | 3 pin, male pins |  |  | http://www.aliexpress.com/item/10pcs-Connector-2-54mm-40-Pin-Male-Single-Row-silver-Pin-Header-Strip-Brand-New/32417455102.html
JINP |  | 2 pin, male pins |  |  | http://www.aliexpress.com/item/10pcs-Connector-2-54mm-40-Pin-Male-Single-Row-silver-Pin-Header-Strip-Brand-New/32417455102.html
LED |  | 2 pin, male pins |  |  | http://www.aliexpress.com/item/10pcs-Connector-2-54mm-40-Pin-Male-Single-Row-silver-Pin-Header-Strip-Brand-New/32417455102.html
LED_SYS |  | SMD LED | 805 |  | http://www.aliexpress.com/item/Free-Shipping-100PCS-0805-Ultra-Bright-SMD-R-G-B-W-Y-LEDs-yellow-blue-White/1596620234.html
PIEZO |  | 2 pin, male pins |  |  | http://www.aliexpress.com/item/10pcs-Connector-2-54mm-40-Pin-Male-Single-Row-silver-Pin-Header-Strip-Brand-New/32417455102.html
R1 | 10K | Resistor | 805 |  | http://www.aliexpress.com/item/0805-SMD-Resistors-10k-10K-ohm-1-8W-5-0805-SMD-Resistors-0805-Chip-resistor-500pcs/852348196.html
R2 | 1K | Resistor | 805 |  | http://www.aliexpress.com/item/0805-SMD-Resistors-1k-1K-ohm-1-8W-5-0805-SMD-Resistors-0805-Chip-resistor-500pcs/852303271.html
R3 | 4.7K | Resistor | 805 |  | http://www.aliexpress.com/item/0805-SMD-Resistors-4K7-4-7K-ohm-1-8W-5-0805-SMD-Resistors-0805-Chip-resistor/852419496.html
R4 | 10K | Resistor | 805 |  | http://www.aliexpress.com/item/0805-SMD-Resistors-10k-10K-ohm-1-8W-5-0805-SMD-Resistors-0805-Chip-resistor-500pcs/852348196.html
R5 | 1K | Resistor | 805 |  | http://www.aliexpress.com/item/0805-SMD-Resistors-1k-1K-ohm-1-8W-5-0805-SMD-Resistors-0805-Chip-resistor-500pcs/852303271.html
R6 | 47 | Resistor | 805 |  | http://www.aliexpress.com/store/product/0805-SMD-Resistors-47R-47-ohm-1-8W-5-0805-SMD-Resistors-0805-Chip-resistor-500pcs/821060_851435603.html
SPI |  | 3 pin, male pins |  |  | http://www.aliexpress.com/item/10pcs-Connector-2-54mm-40-Pin-Male-Single-Row-silver-Pin-Header-Strip-Brand-New/32417455102.html
SWITCH |  | 2 pin, male pins |  |  | http://www.aliexpress.com/item/10pcs-Connector-2-54mm-40-Pin-Male-Single-Row-silver-Pin-Header-Strip-Brand-New/32417455102.html
U$1 |  | 9 pin, male 90 deg pins |  |  | http://www.aliexpress.com/item/10PCS-1x40-Pin-2-54mm-Right-Angle-Single-Row-Male-Pin-Header-Connector/32403777838.html
U$3 |  | 9 pin, male 90 deg pins |  |  | http://www.aliexpress.com/item/10PCS-1x40-Pin-2-54mm-Right-Angle-Single-Row-Male-Pin-Header-Connector/32403777838.html
U$4 |  | 9 pin, male pins |  |  | http://www.aliexpress.com/item/10pcs-Connector-2-54mm-40-Pin-Male-Single-Row-silver-Pin-Header-Strip-Brand-New/32417455102.html
U1 |  | EEPROM memory | SO-08 | 512K flash memory | https://www.digikey.com/product-detail/en/AT25DF512C-SSHN-B/1265-1179-5-ND/4901487
U2 |  | ATSHA204A | SOT23-3 | Crypto chip | https://www.digikey.com/product-detail/en/ATSHA204A-STUCZ-T/ATSHA204A-STUCZ-TCT-ND/4814557
U3 |  | 3.3V Arduino Pro Mini Clone | PRO_MINI_CLONE_NO_PROG | ABK Pro-Mini Arduino Clone | http://www.aliexpress.com/item/Free-Shipping-1pcs-pro-mini-atmega328-Pro-Mini-328-Mini-ATMEGA328-3-3V-8MHz-for-Arduino/32340942669.html
U4 |  | AMS1117 3.3V | SOT223 |  | http://www.aliexpress.com/item/50pcs-AMS1117-3-3-AMS1117-LM1117-1117-3-3V-1A-Voltage-Regulator/32347685609.html
U5 |  | RFM69W radio |  |  | http://www.ebay.com/itm/181170695434?_trksid=p2057872.m2749.l2649&ssPageName=STRK%3AMEBIDX%3AIT
Miscellaneous Items
Case |  |  |  |  | http://www.aliexpress.com/item/Wholesale-electrical-junction-box-10pcs-105-65-40mm-plastic-instrument-box-plastic-box-electronic-project-box/1986580384.html
Antenna |  |  |  |  | http://www.aliexpress.com/item/20pcs-lot-helical-antenna-SW915-TH12-915MHz-12-5mm-Copper-spring-antenna-for-wireless-RF-module/2043535002.html
Piezo |  | 3V buzzer |  |  | http://www.ebay.com/itm/181502256974?_trksid=p2057872.m2749.l2649&ssPageName=STRK%3AMEBIDX%3AIT

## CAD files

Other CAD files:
sketchup/input.skp
sketchup/relay_ac.skp
sketchup/relay_dc.skp
sketchup/sensor.skp
sketchup/valve.skp

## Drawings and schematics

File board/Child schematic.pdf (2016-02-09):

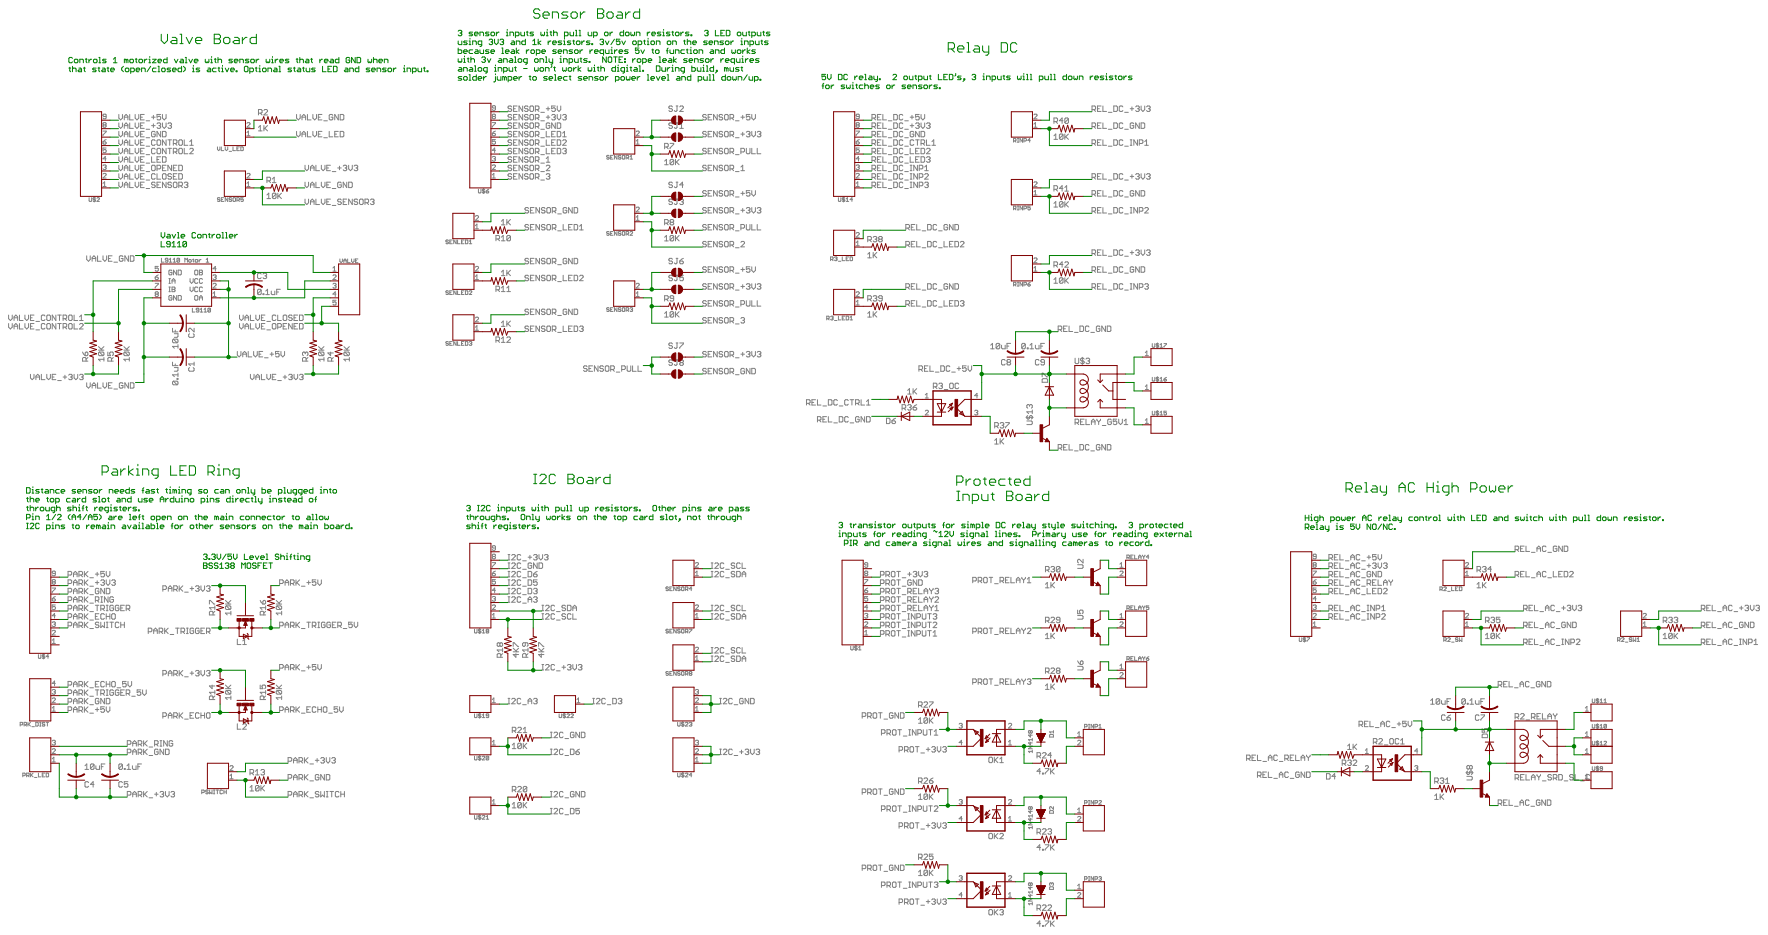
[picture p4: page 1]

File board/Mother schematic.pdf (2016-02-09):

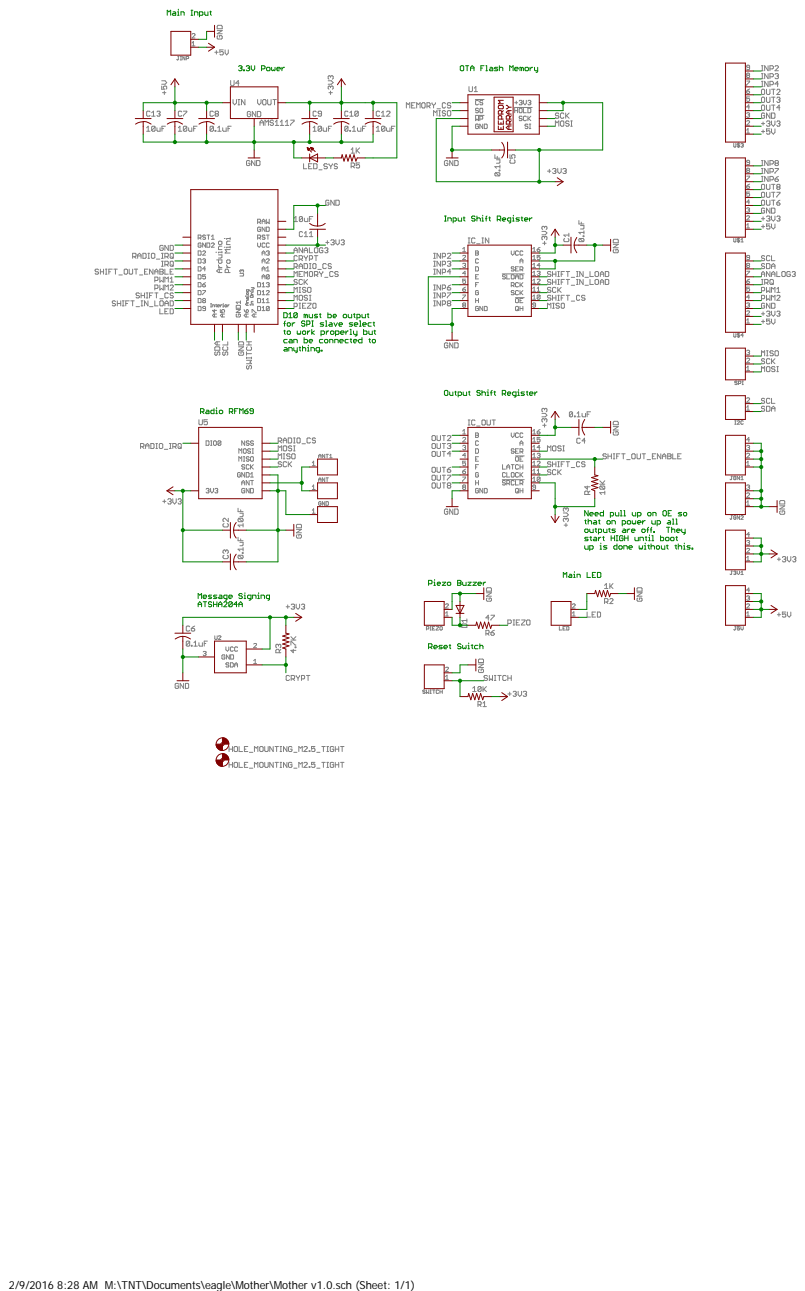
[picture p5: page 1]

2/9/2016 8:28 AM M:\TNT\Documents\eagle\Mother\Mother v1.0.sch (Sheet: 1/1)

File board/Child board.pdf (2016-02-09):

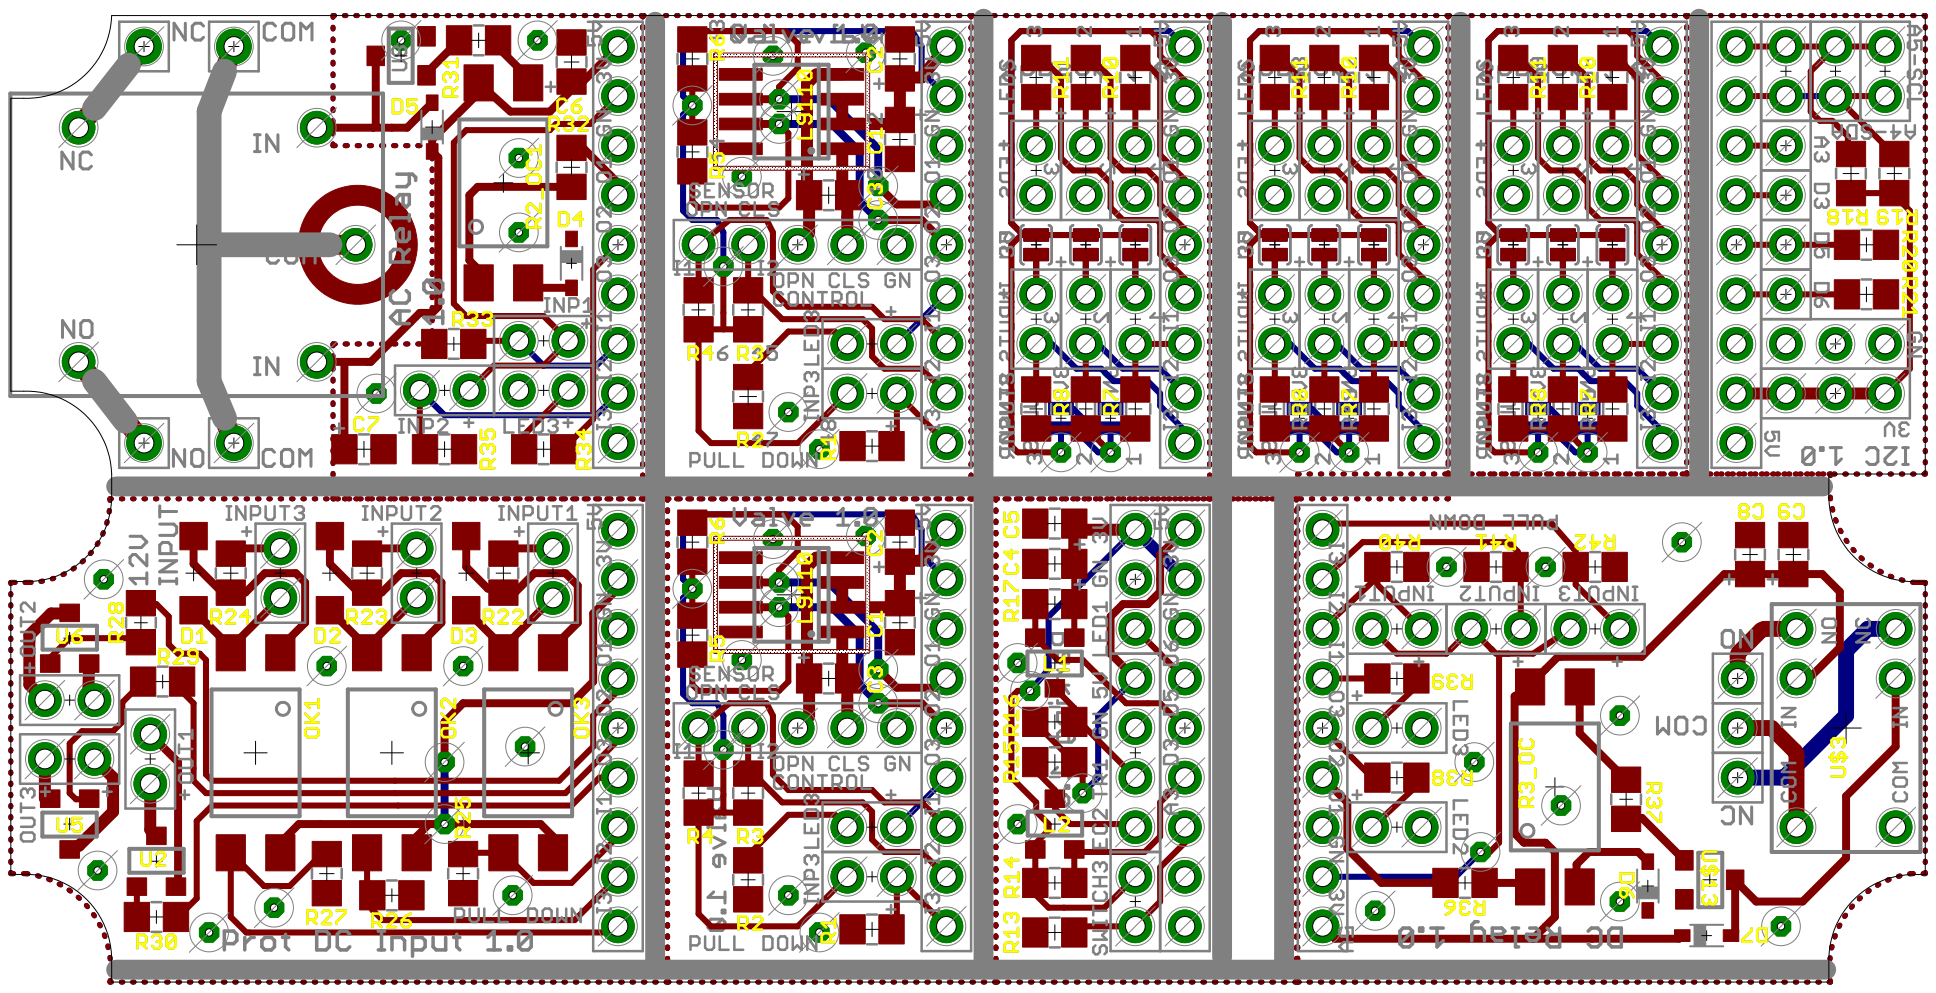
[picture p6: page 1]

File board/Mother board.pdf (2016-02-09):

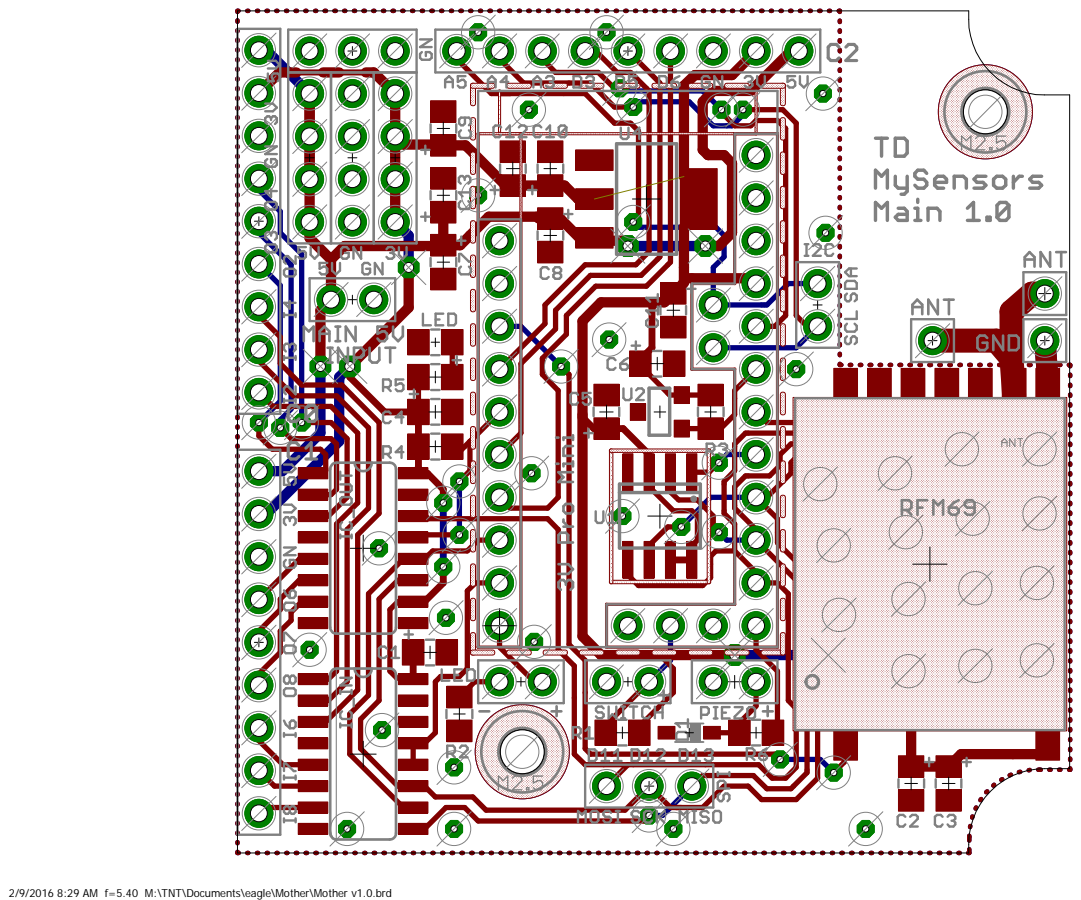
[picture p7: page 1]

2/9/2016 8:29 AM f=5.40 M:\TNT\Documents\eagle\Mother\Mother v1.0.brd

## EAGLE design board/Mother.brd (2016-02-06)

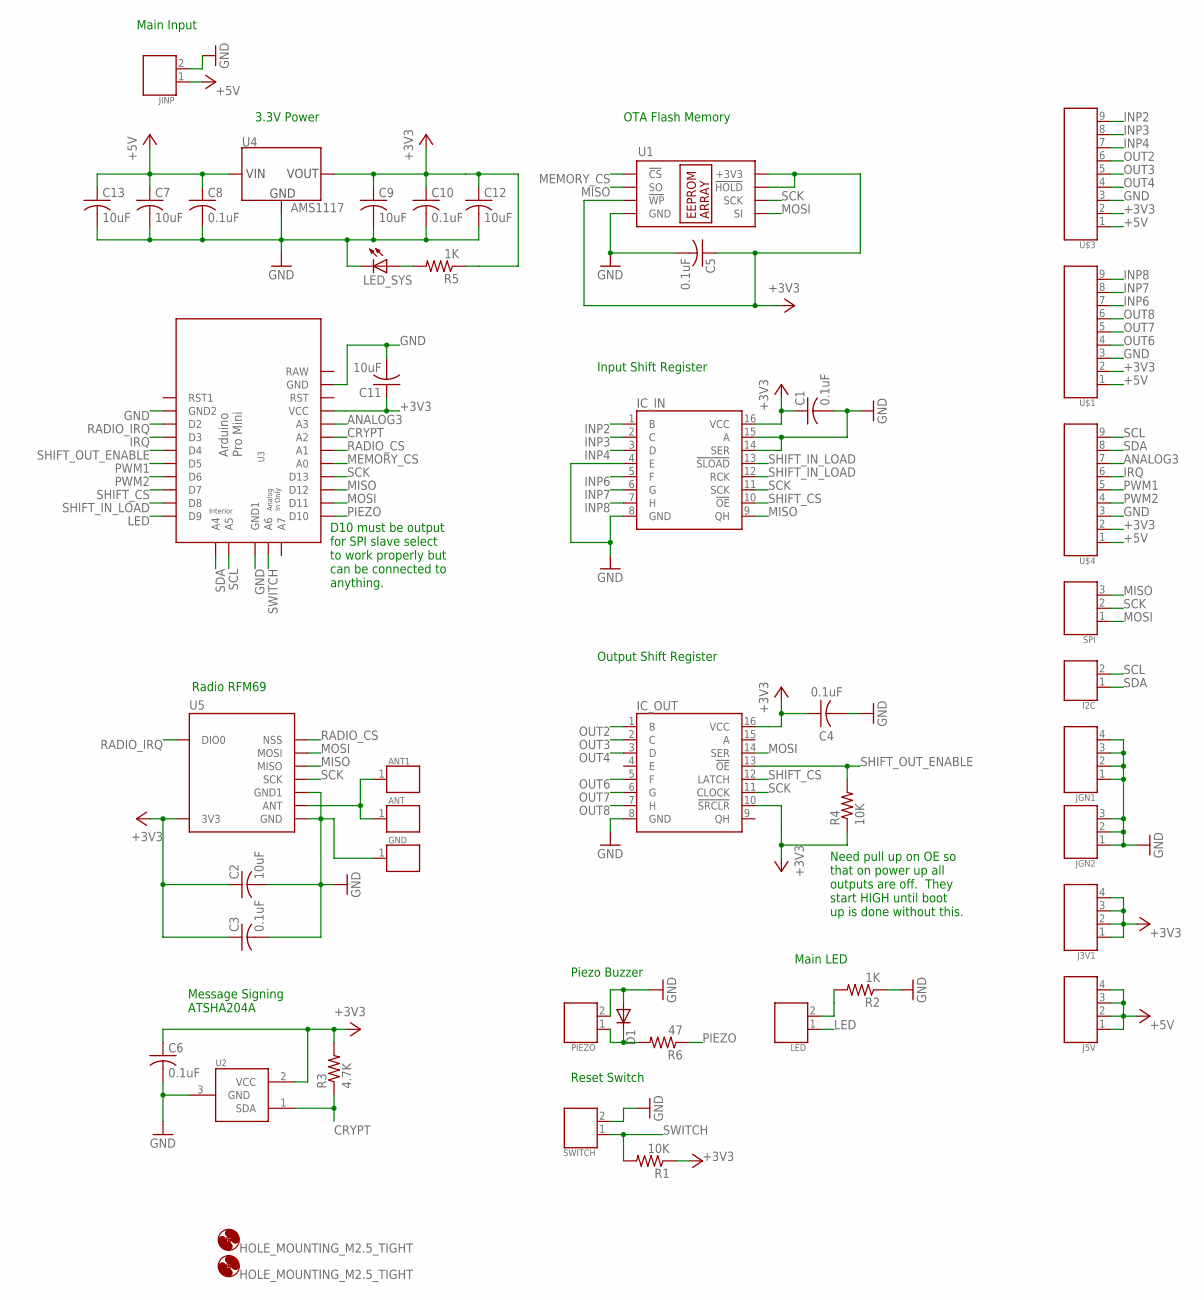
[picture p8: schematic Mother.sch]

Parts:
ANT, ANT1: CONNECTOR_1DUPONT; DUPONT_1
C1, C3, C4, C5, C6, C8, C10: 0.1uF; CAP_0805
C2, C7, C9, C11, C12, C13: 10uF; CAP_0805
D1: DIODESOD323; SOD323
GND: CONNECTOR_1DUPONT; DUPONT_1
H1, H2: HOLE_MOUNTING_M2.5_TIGHT; HOLE_M2.5PAN_TIGHT
I2C: CONNECTOR_2DUPONT; DUPONT_2
IC_IN: IC_MM74HC589SO16; SO16
IC_OUT: IC_SN74HC595; SO16
J3V1, J5V: CONNECTOR_4DUPONT; DUPONT_4
JGN1: CONNECTOR_4DUPONT; DUPONT_4
JGN2: CONNECTOR_3DUPONT; DUPONT_3
JINP: CONNECTOR_2DUPONT; DUPONT_2
LED: CONNECTOR_2DUPONT; DUPONT_2
LED_SYS: LED; LED_0805
PIEZO: CONNECTOR_2DUPONT; DUPONT_2
R1, R4: 10K; R_0805
R2, R5: 1K; R_0805
R3: 4.7K; R_0805
R6: 47; R_0805
SPI: CONNECTOR_3DUPONT; DUPONT_3
SWITCH: CONNECTOR_2DUPONT; DUPONT_2
U1: IC_EEPROM; SO-08
U2: IC_ATSHA204A_CRYPT; SOT23-3
U3: ARD_PRO_MINI_CLONE_NOPROG; PRO_MINI_CLONE_NO_PROG
U4: AMS1117; SOT223
U5: RADIO_RFM69W_MIN_PAD; RFM69W_MIN_PAD
U$1, U$3: CONNECTOR_9DUP_MALE90; DUPONT_MALE90_9
U$4: CONNECTOR_9DUPONT; DUPONT_9

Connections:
+3V3: C1.1, C2.1, C3.1, C4.1, C5.1, C6.1, C9.1, C10.1, C11.1, C12.1, IC_IN.16 (VCC), IC_OUT.10 (!SRCLR), IC_OUT.16 (VCC), J3V1.1, J3V1.2, J3V1.3, J3V1.4, R1.1, R3.2, R4.1, R5.1, U1.3 (!WP), U1.7 (!HOLD), U1.8 (+3V3), U2.2 (VCC), U3.P$19 (VCC), U4.2 (VOUT), U4.4 (VOUT), U5.8 (3V3), U$1.2, U$3.2, U$4.2
+5V: C7.1, C8.1, C13.1, J5V.1, J5V.2, J5V.3, J5V.4, JINP.1, U4.3 (VIN), U$1.1, U$3.1, U$4.1
ANALOG3: U3.P$18 (A3), U$4.7
CRYPT: R3.1, U2.1 (SDA), U3.P$17 (A2)
GND: C1.2, C2.2, C3.2, C4.2, C5.2, C6.2, C7.2, C8.2, C9.2, C10.2, C11.2, C12.2, C13.2, D1.A, GND.1, IC_IN.4 (E), IC_IN.8 (GND), IC_IN.14 (SER), IC_IN.15 (A), IC_OUT.8 (GND), JGN1.1, JGN1.2, JGN1.3, JGN1.4, JGN2.1, JGN2.2, JGN2.3, JINP.2, LED_SYS.2 (C), PIEZO.2, R2.1, SWITCH.2, U1.4 (GND), U2.3 (GND), U3.P$2 (GND2), U3.P$21 (GND), U3.P$27 (GND1), U4.1 (GND), U5.9 (GND), U5.11 (GND1), U$1.3, U$3.3, U$4.3
INP2: IC_IN.1 (B), U$3.9
INP3: IC_IN.2 (C), U$3.8
INP4: IC_IN.3 (D), U$3.7
INP6: IC_IN.5 (F), U$1.7
INP7: IC_IN.6 (G), U$1.8
INP8: IC_IN.7 (H), U$1.9
IRQ: U3.P$4 (D3), U$4.6
LED: LED.1, U3.P$10 (D9)
MEMORY_CS: U1.1 (!CS), U3.P$15 (A0)
MISO: IC_IN.9 (QH), SPI.3, U1.2 (SO), U3.P$13 (D12), U5.13 (MISO)
MOSI: IC_OUT.14 (SER), SPI.1, U1.5 (SI), U3.P$12 (D11), U5.14 (MOSI)
unnamed: LED.2, R2.2
unnamed: LED_SYS.1 (A), R5.2
unnamed: D1.C, PIEZO.1, R6.2
unnamed: ANT.1, ANT1.1, U5.10 (ANT)
OUT2: IC_OUT.1 (B), U$3.6
OUT3: IC_OUT.2 (C), U$3.5
OUT4: IC_OUT.3 (D), U$3.4
OUT6: IC_OUT.5 (F), U$1.4
OUT7: IC_OUT.6 (G), U$1.5
OUT8: IC_OUT.7 (H), U$1.6
PIEZO: R6.1, U3.P$11 (D10)
PWM1: U3.P$6 (D5), U$4.5
PWM2: U3.P$7 (D6), U$4.4
RADIO_CS: U3.P$16 (A1), U5.15 (NSS)
RADIO_IRQ: U3.P$3 (D2), U5.2 (DIO0)
RAW: U3.P$22 (RAW)
SCK: IC_IN.11 (SCK), IC_OUT.11 (CLOCK), SPI.2, U1.6 (SCK), U3.P$14 (D13), U5.12 (SCK)
SCL: I2C.2, U3.P$24 (A5), U$4.9
SDA: I2C.1, U3.P$23 (A4), U$4.8
SHIFT_CS: IC_IN.10 (!OE), IC_OUT.12 (LATCH), U3.P$8 (D7)
SHIFT_IN_LOAD: IC_IN.12 (RCK), IC_IN.13 (!SLOAD), U3.P$9 (D8)
SHIFT_OUT_ENABLE: IC_OUT.13 (!OE), R4.2, U3.P$5 (D4)
SWITCH: R1.2, SWITCH.1, U3.P$26 (A6)

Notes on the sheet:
Message Signing ATSHA204A
3.3V Power
Reset Switch
Input Shift Register
Piezo Buzzer
Radio RFM69
OTA Flash Memory
D10 must be output for SPI slave select to work properly but can be connected to anything.
Output Shift Register
Need pull up on OE so that on power up all outputs are off. They start HIGH until boot up is done without this.
Main LED
Main Input

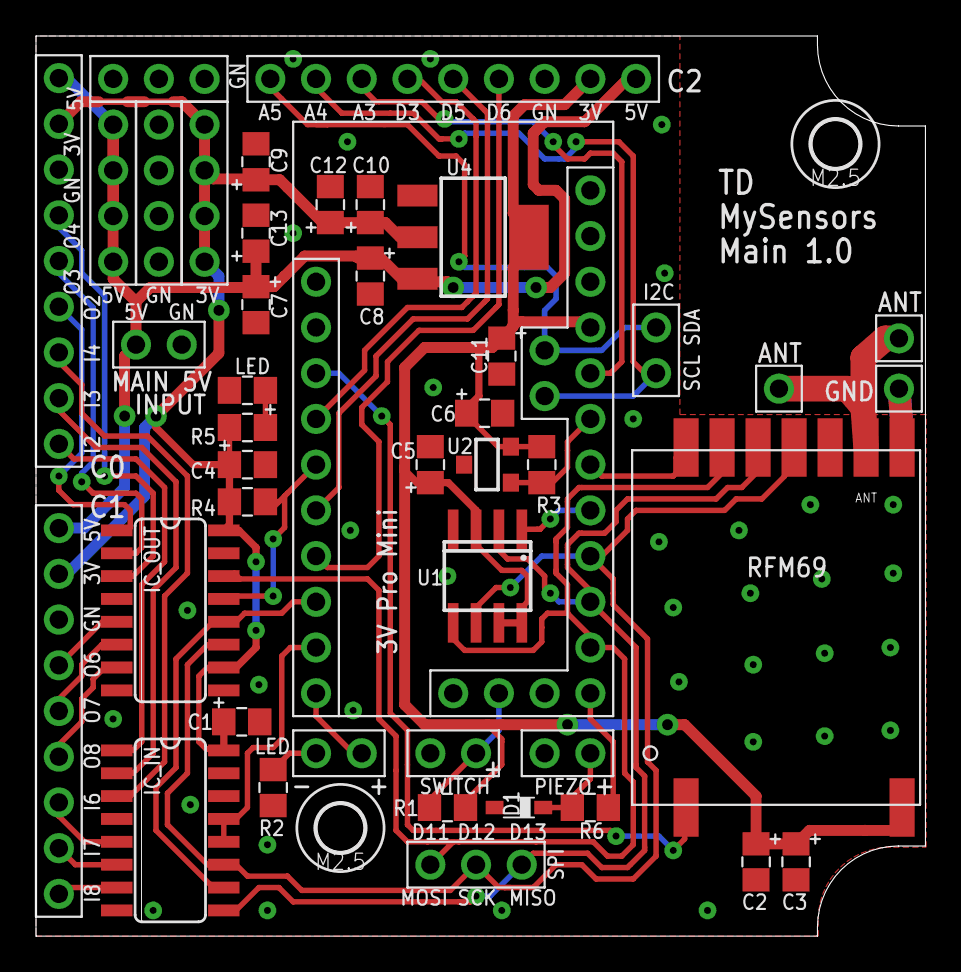
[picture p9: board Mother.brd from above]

Board: 4 copper layers, 49.4 x 50.0 mm, 46 parts (0 on the bottom side), 38 nets.

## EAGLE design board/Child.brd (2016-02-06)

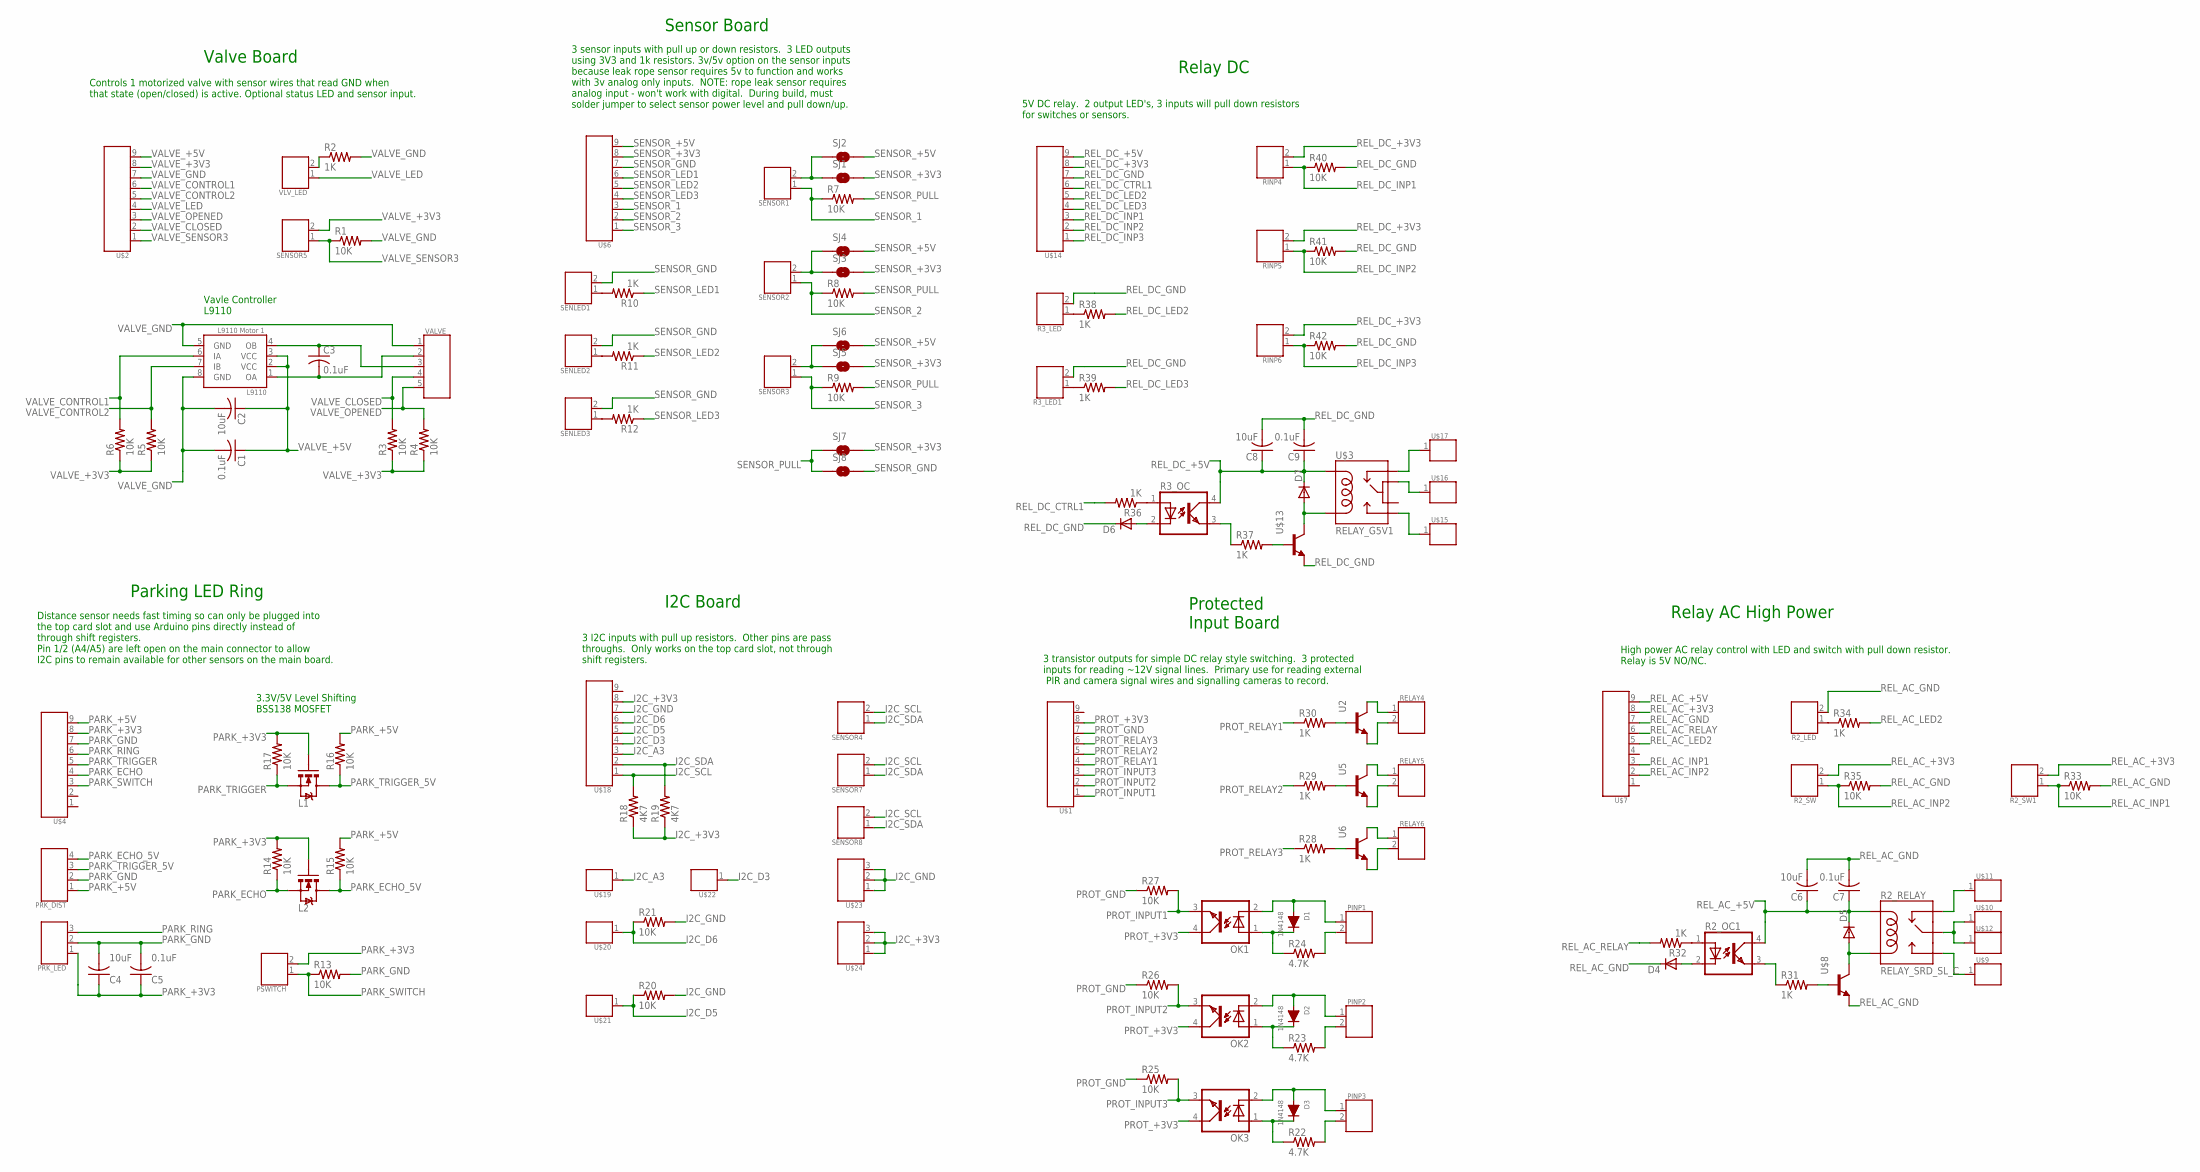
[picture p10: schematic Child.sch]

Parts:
C1, C3, C5, C7, C9: 0.1uF; CAP_0805
C2, C4, C6, C8: 10uF; CAP_0805
D1, D2, D3: 1N4148; SOD123
D4, D5, D6, D7: DIODESOD323; SOD323
L1, L2: MOSFET-NCHANNELSMD; SOT23-3
L9110: L9110 Motor 1; SO-08
OK1, OK2, OK3: PC817SOP; SO-4_PC817
PINP1, PINP2, PINP3: CONNECTOR_2DUPONT; DUPONT_2
PRK_DIST: CONNECTOR_4DUPONT; DUPONT_4
PRK_LED: CONNECTOR_3DUPONT; DUPONT_3
PSWITCH: CONNECTOR_2DUPONT; DUPONT_2
R1, R3, R4, R5, R6, R7, R8, R9, R13, R14, R15, R16, R17, R20, R21, R25, R26, R27, R33, R35, R40, R41, R42: 10K; R_0805
R2, R10, R11, R12, R28, R29, R30, R31, R32, R34, R36, R37, R38, R39: 1K; R_0805
R2_LED, R2_SW, R2_SW1, R3_LED, R3_LED1: CONNECTOR_2DUPONT; DUPONT_2
R2_OC1, R3_OC: PC817SOP; SO-4_PC817
R2_RELAY: RELAY_SRD_SL_C; RELAY_SRD-SL-C
R18, R19: 4K7; R_0805
R22, R23, R24: 4.7K; R_0805
RELAY4, RELAY5, RELAY6: CONNECTOR_2DUPONT; DUPONT_2
RINP4, RINP5, RINP6: CONNECTOR_2DUPONT; DUPONT_2
SENLED1, SENLED2, SENLED3: CONNECTOR_2DUPONT; DUPONT_2
SENSOR1, SENSOR2, SENSOR3, SENSOR4, SENSOR5, SENSOR7, SENSOR8: CONNECTOR_2DUPONT; DUPONT_2
SJ1, SJ2, SJ3, SJ4, SJ5, SJ6, SJ7, SJ8: JUMPER-PAD-2-NOYES_SILK; PAD-JUMPER-2-NO_YES_SILK
U2, U5, U6: TRANSISTORSMD; SOT23-3
U$1, U$2, U$6, U$7, U$14, U$18: CONNECTOR_9DUP_FEM90; DUPONT_FEM90_9
U$3: RELAY_G5V1; RELAY-G5V
U$4: CONNECTOR_9DUPONT; DUPONT_9
U$8, U$13: TRANSISTORSMD; SOT23-3
U$9, U$10, U$11, U$12: CONNECTOR_1DUP_LARGE; DUPONT_1_LRG
U$15, U$16, U$17, U$19, U$20, U$21, U$22: CONNECTOR_1DUPONT; DUPONT_1
U$23, U$24: CONNECTOR_3DUPONT; DUPONT_3
VALVE: CONNECTOR_5DUPONT; DUPONT_5
VLV_LED: CONNECTOR_2DUPONT; DUPONT_2

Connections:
I2C_+3V3: R18.1, R19.1, U$18.8, U$24.1, U$24.2, U$24.3
I2C_A3: U$18.3, U$19.1
I2C_D3: U$18.4, U$22.1
I2C_D5: R20.1, U$18.5, U$21.1
I2C_D6: R21.1, U$18.6, U$20.1
I2C_GND: R20.2, R21.2, U$18.7, U$23.1, U$23.2, U$23.3
I2C_SCL: R18.2, SENSOR4.2, SENSOR7.2, SENSOR8.2, U$18.1
I2C_SDA: R19.2, SENSOR4.1, SENSOR7.1, SENSOR8.1, U$18.2
unnamed: C3.1, L9110.4 (OB), VALVE.3
unnamed: C3.2, L9110.1 (OA), VALVE.2
unnamed: R2.1, VLV_LED.2
unnamed: D1.C (K), OK1.1, R24.1
unnamed: D1.A, OK1.2, PINP1.1
unnamed: PINP1.2, R24.2
unnamed: D2.C (K), OK2.1, R23.1
unnamed: D2.A, OK2.2, PINP2.1
unnamed: PINP2.2, R23.2
unnamed: D3.C (K), OK3.1, R22.1
unnamed: D3.A, OK3.2, PINP3.1
unnamed: PINP3.2, R22.2
unnamed: R10.2, SENLED1.1
unnamed: R11.2, SENLED2.1
unnamed: R12.2, SENLED3.1
unnamed: R30.2, U2.1 (BASE)
unnamed: RELAY4.1, U2.3 (COLLECTOR)
unnamed: RELAY4.2, U2.2 (EMITTER)
unnamed: SENSOR3.2, SJ5.1, SJ6.1
unnamed: SENSOR2.2, SJ3.1, SJ4.1
unnamed: R29.2, U5.1 (BASE)
unnamed: R28.2, U6.1 (BASE)
unnamed: R3_LED1.1, R39.1
unnamed: RELAY5.1, U5.3 (COLLECTOR)
unnamed: RELAY5.2, U5.2 (EMITTER)
unnamed: RELAY6.1, U6.3 (COLLECTOR)
unnamed: RELAY6.2, U6.2 (EMITTER)
unnamed: R2_LED.1, R34.1
unnamed: D5.A, R2_RELAY.2 (COIL_B), U$8.3 (COLLECTOR)
unnamed: R31.2, U$8.1 (BASE)
unnamed: R2_OC1.3 (EMIT), R31.1
unnamed: D4.A, R2_OC1.2
unnamed: R2_OC1.1, R32.1
unnamed: D7.A, U$3.9, U$13.3 (COLLECTOR)
unnamed: R37.2, U$13.1 (BASE)
unnamed: R3_OC.3 (EMIT), R37.1
unnamed: D6.A, R3_OC.2
unnamed: R3_OC.1, R36.1
unnamed: R3_LED.1, R38.1
unnamed: U$3.5, U$16.1
unnamed: SENSOR1.2, SJ1.1, SJ2.1
PARK_+3V3: C4.1, C5.1, L1.1 (G), L2.1 (G), PRK_LED.1, PSWITCH.2, R14.2, R17.2, U$4.8
PARK_+5V: PRK_DIST.1, R15.2, R16.2, U$4.9
PARK_ECHO: L2.2 (S), R14.1, U$4.4
PARK_ECHO_5V: L2.3 (D), PRK_DIST.4, R15.1
PARK_GND: C4.2, C5.2, PRK_DIST.2, PRK_LED.2, R13.2, U$4.7
PARK_RING: PRK_LED.3, U$4.6
PARK_SWITCH: PSWITCH.1, R13.1, U$4.3
PARK_TRIGGER: L1.2 (S), R17.1, U$4.5
PARK_TRIGGER_5V: L1.3 (D), PRK_DIST.3, R16.1
PROT_+3V3: OK1.4 (COL), OK2.4 (COL), OK3.4 (COL), U$1.8
PROT_GND: R25.1, R26.1, R27.1, U$1.7
PROT_INPUT1: OK1.3 (EMIT), R27.2, U$1.1
PROT_INPUT2: OK2.3 (EMIT), R26.2, U$1.2
PROT_INPUT3: OK3.3 (EMIT), R25.2, U$1.3
PROT_RELAY1: R30.1, U$1.4
PROT_RELAY2: R29.1, U$1.5
PROT_RELAY3: R28.1, U$1.6
R2_COM: R2_RELAY.3 (COM), U$10.1, U$12.1
R2_NC: R2_RELAY.5 (NC), U$11.1
R2_NC1: U$3.1, U$17.1
R2_NO: R2_RELAY.4 (NO), U$9.1
R2_NO1: U$3.10, U$15.1
REL_AC_+3V3: R2_SW.2, R2_SW1.2, U$7.8
REL_AC_+5V: C6.1, C7.1, D5.C, R2_OC1.4 (COL), R2_RELAY.1 (COIL_A), U$7.9
REL_AC_GND: C6.2, C7.2, D4.C, R2_LED.2, R33.2, R35.2, U$7.7, U$8.2 (EMITTER)
REL_AC_INP1: R2_SW1.1, R33.1, U$7.3
REL_AC_INP2: R2_SW.1, R35.1, U$7.2
REL_AC_LED2: R34.2, U$7.5
REL_AC_RELAY: R32.2, U$7.6
REL_DC_+3V3: RINP4.2, RINP5.2, RINP6.2, U$14.8
REL_DC_+5V: C8.1, C9.1, D7.C, R3_OC.4 (COL), U$3.2, U$14.9
REL_DC_CTRL1: R36.2, U$14.6
REL_DC_GND: C8.2, C9.2, D6.C, R3_LED.2, R3_LED1.2, R40.2, R41.2, R42.2, U$13.2 (EMITTER), U$14.7
REL_DC_INP1: R40.1, RINP4.1, U$14.3
REL_DC_INP2: R41.1, RINP5.1, U$14.2
REL_DC_INP3: R42.1, RINP6.1, U$14.1
REL_DC_LED2: R38.2, U$14.5
REL_DC_LED3: R39.2, U$14.4
SENSOR_1: R7.1, SENSOR1.1, U$6.3
SENSOR_2: R8.1, SENSOR2.1, U$6.2
SENSOR_3: R9.1, SENSOR3.1, U$6.1
SENSOR_+3V3: SJ1.2, SJ3.2, SJ5.2, SJ7.2, U$6.8
SENSOR_+5V: SJ2.2, SJ4.2, SJ6.2, U$6.9
SENSOR_GND: SENLED1.2, SENLED2.2, SENLED3.2, SJ8.2, U$6.7
SENSOR_LED1: R10.1, U$6.6
SENSOR_LED2: R11.1, U$6.5
SENSOR_LED3: R12.1, U$6.4
SENSOR_PULL: R7.2, R8.2, R9.2, SJ7.1, SJ8.1
VALVE_+3V3: R3.1, R4.1, R5.1, R6.1, SENSOR5.2, U$2.8
VALVE_+5V: C1.1, C2.1, L9110.2 (VCC), L9110.3 (VCC), U$2.9
VALVE_CLOSED: R3.2, U$2.2, VALVE.4
VALVE_CONTROL1: L9110.6 (IA), R6.2, U$2.6
VALVE_CONTROL2: L9110.7 (IB), R5.2, U$2.5
VALVE_GND: C1.2, C2.2, L9110.5 (GND), L9110.8 (GND), R1.2, R2.2, U$2.7, VALVE.1
VALVE_LED: U$2.4, VLV_LED.1
VALVE_OPENED: R4.2, U$2.3, VALVE.5
VALVE_SENSOR3: R1.1, SENSOR5.1, U$2.1

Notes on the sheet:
Vavle Controller L9110
Valve Board
Protected Input Board
Sensor Board
3.3V/5V Level Shifting BSS138 MOSFET
Parking LED Ring
Distance sensor needs fast timing so can only be plugged into the top card slot and use Arduino pins directly instead of through shift registers. Pin 1/2 (A4/A5) are left open on the main connector to allow I2C pins to remain available for other sensors on the main board.
Relay AC High Power
Relay DC
I2C Board
Controls 1 motorized valve with sensor wires that read GND when that state (open/closed) is active. Optional status LED and sensor input.
3 sensor inputs with pull up or down resistors. 3 LED outputs using 3V3 and 1k resistors. 3v/5v option on the sensor inputs because leak rope sensor requires 5v to function and works with 3v analog only inputs. NOTE: rope leak sensor requires analog input - won't work with digital. During build, mu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
3 I2C inputs with pull up resistors. Other pins are pass throughs. Only works on the top card slot, not through shift registers.
High power AC relay control with LED and switch with pull down resistor. Relay is 5V NO/NC.
5V DC relay. 2 output LED's, 3 inputs will pull down resistors for switches or sensors.
3 transistor outputs for simple DC relay style switching. 3 protected inputs for reading ~12V signal lines. Primary use for reading external PIR and camera signal wires and signalling cameras to record.

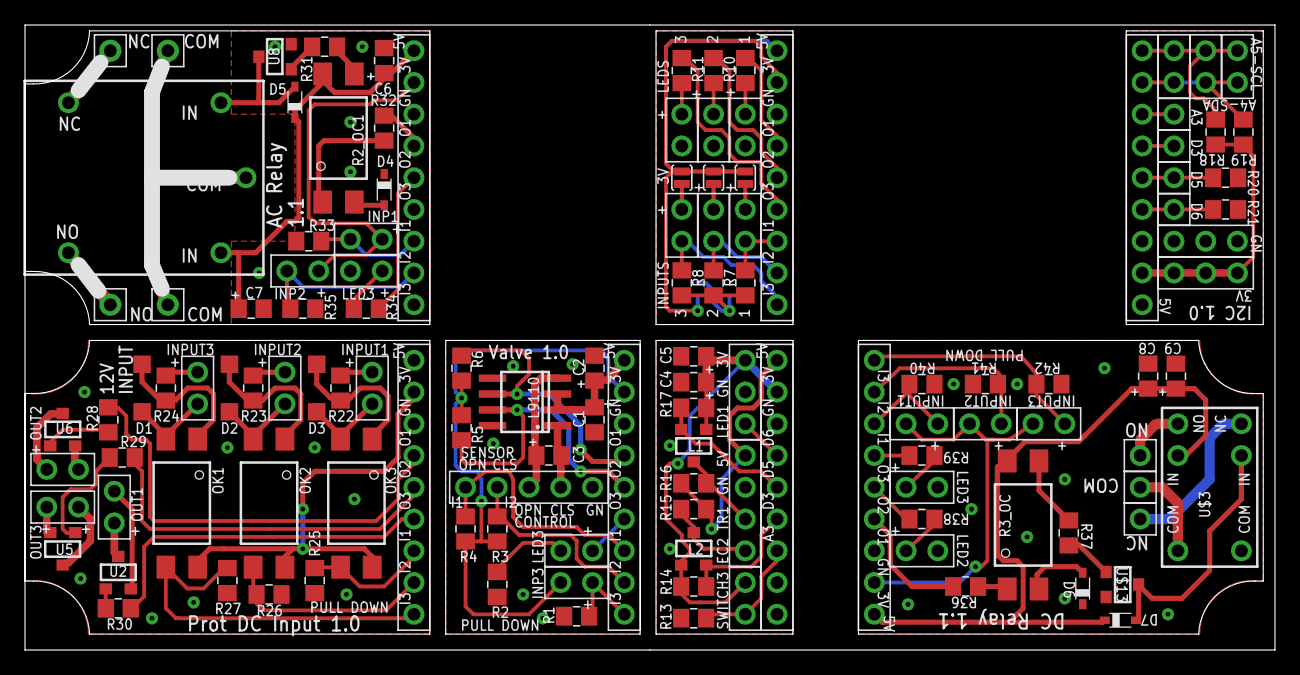
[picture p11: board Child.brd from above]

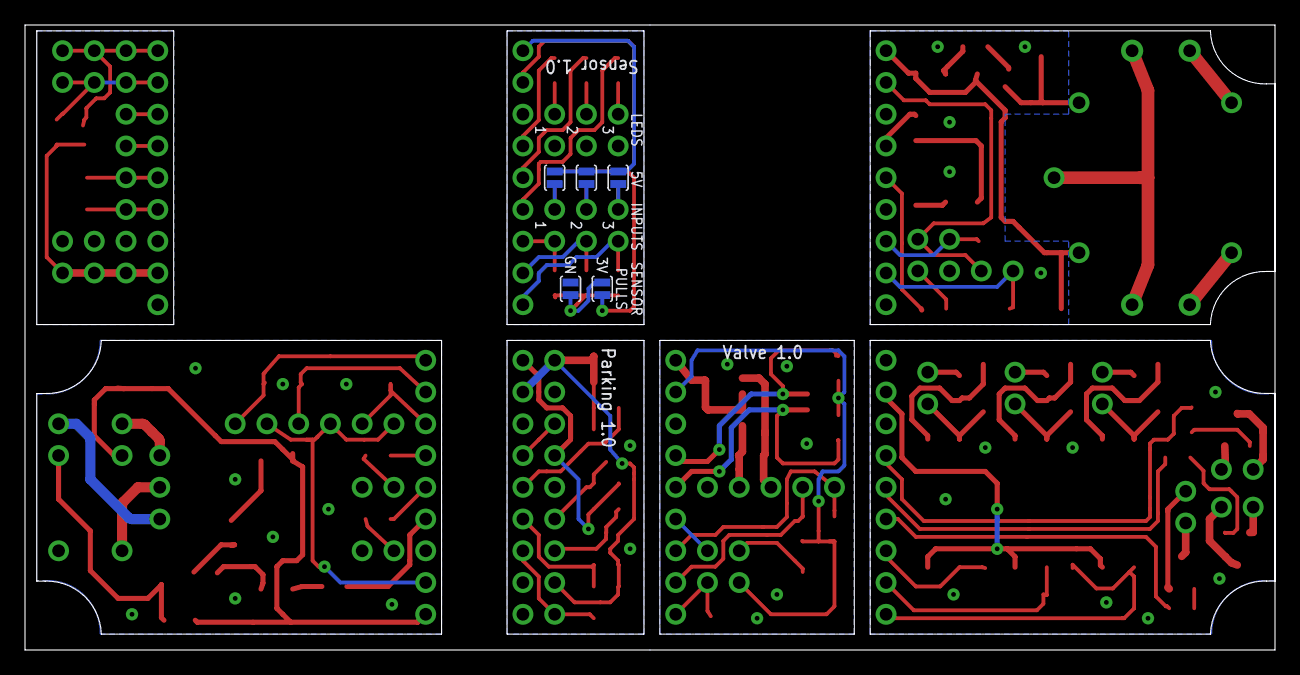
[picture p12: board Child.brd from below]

Board: 4 copper layers, 100.0 x 50.0 mm, 130 parts (5 on the bottom side), 106 nets.

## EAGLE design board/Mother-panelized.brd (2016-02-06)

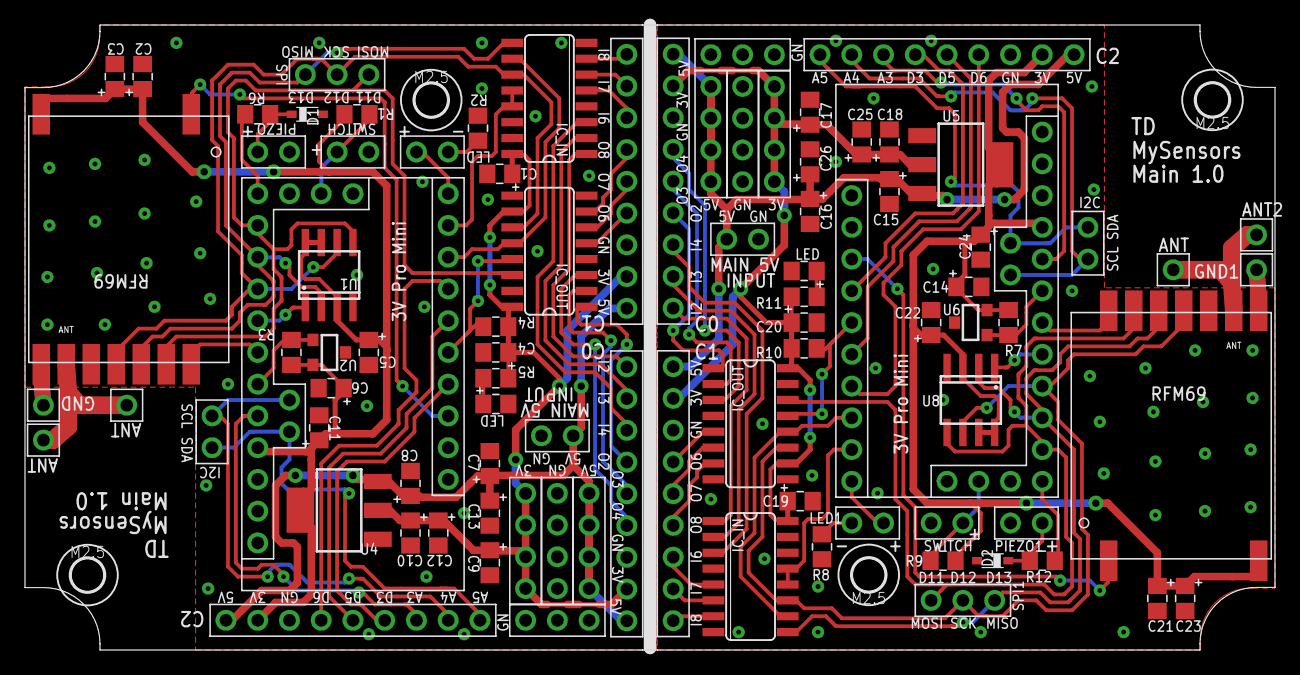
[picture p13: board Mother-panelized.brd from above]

Board: 4 copper layers, 100.0 x 50.0 mm, 92 parts (0 on the bottom side), 76 nets.

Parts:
ANT, ANT1, ANT2, ANT3: DUPONT_1
C1, C3, C4, C5, C6, C8, C10, C14, C15, C18, C19, C20, C22, C23: 0.1uF; CAP_0805
C2, C7, C9, C11, C12, C13, C16, C17, C21, C24, C25, C26: 10uF; CAP_0805
D1, D2: SOD323
GND, GND1: DUPONT_1
H1, H2, H3, H4: HOLE_MOUNTING_M2.5_TIGHT; HOLE_M2.5PAN_TIGHT
I2C, I2C1: DUPONT_2
IC_IN, IC_IN1: SO16
IC_OUT, IC_OUT1: SO16
J3V1, J3V2, J5V, J5V1: DUPONT_4
JGN1, JGN4: DUPONT_4
JGN2, JGN3: DUPONT_3
JINP, JINP1: DUPONT_2
LED, LED1: DUPONT_2
LED_SYS, LED_SYS1: LED_0805
PIEZO, PIEZO1: DUPONT_2
R1, R4, R9, R10: 10K; R_0805
R2, R5, R8, R11: 1K; R_0805
R3, R7: 4.7K; R_0805
R6, R12: 220; R_0805
SPI, SPI1: DUPONT_3
SWITCH, SWITCH1: DUPONT_2
U1, U8: SO-08
U2, U6: SOT23-3
U3, U7: PRO_MINI_CLONE
U4, U5: AMS1117; SOT223
U$1, U$3, U$6, U$7: DUPONT_MALE90_9
U$2, U$5: RADIO_RFM69W_MS; RFM69W_MS
U$4, U$8: DUPONT_9

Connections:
+3V1: C14.1, C17.1, C18.1, C19.1, C20.1, C21.1, C22.1, C23.1, C24.1, C25.1, IC_IN1.16, IC_OUT1.10, IC_OUT1.16, J3V2.1, J3V2.2, J3V2.3, J3V2.4, R7.2, R9.1, R10.1, R11.1, U5.2, U5.4, U6.2, U7.P$19, U8.3, U8.7, U8.8, U$5.8, U$6.2, U$7.2, U$8.2
+3V3: C1.1, C2.1, C3.1, C4.1, C5.1, C6.1, C9.1, C10.1, C11.1, C12.1, IC_IN.16, IC_OUT.10, IC_OUT.16, J3V1.1, J3V1.2, J3V1.3, J3V1.4, R1.1, R3.2, R4.1, R5.1, U1.3, U1.7, U1.8, U2.2, U3.P$19, U4.2, U4.4, U$1.2, U$2.8, U$3.2, U$4.2
+5V: C7.1, C8.1, C13.1, J5V.1, J5V.2, J5V.3, J5V.4, JINP.1, U4.3, U$1.1, U$3.1, U$4.1
+5V1: C15.1, C16.1, C26.1, J5V1.1, J5V1.2, J5V1.3, J5V1.4, JINP1.1, U5.3, U$6.1, U$7.1, U$8.1
ANALOG1: U7.P$18, U$8.7
ANALOG3: U3.P$18, U$4.7
CRYPT: R3.1, U2.1, U3.P$17
CRYPT1: R7.1, U6.1, U7.P$17
GND: C1.2, C2.2, C3.2, C4.2, C5.2, C6.2, C7.2, C8.2, C9.2, C10.2, C11.2, C12.2, C13.2, D1.A, GND.1, IC_IN.4, IC_IN.8, IC_IN.14, IC_IN.15, IC_OUT.8, JGN1.1, JGN1.2, JGN1.3, JGN1.4, JGN2.1, JGN2.2, JGN2.3, JINP.2, LED_SYS.2, PIEZO.2, R2.1, SWITCH.2, U1.4, U2.3, U3.P$2, U3.P$21, U3.P$27, U4.1, U$1.3, U$2.9, U$2.11, U$3.3, U$4.3
GND1: C14.2, C15.2, C16.2, C17.2, C18.2, C19.2, C20.2, C21.2, C22.2, C23.2, C24.2, C25.2, C26.2, D2.A, GND1.1, IC_IN1.4, IC_IN1.8, IC_IN1.14, IC_IN1.15, IC_OUT1.8, JGN3.1, JGN3.2, JGN3.3, JGN4.1, JGN4.2, JGN4.3, JGN4.4, JINP1.2, LED_SYS1.2, PIEZO1.2, R8.1, SWITCH1.2, U5.1, U6.3, U7.P$2, U7.P$21, U7.P$27, U8.4, U$5.9, U$5.11, U$6.3, U$7.3, U$8.3
INP1: IC_IN1.5, U$6.7
INP2: IC_IN.1, U$3.9
INP3: IC_IN.2, U$3.8
INP4: IC_IN.3, U$3.7
INP5: IC_IN1.7, U$6.9
INP6: IC_IN.5, U$1.7
INP7: IC_IN.6, U$1.8
INP8: IC_IN.7, U$1.9
INP9: IC_IN1.3, U$7.7
INP10: IC_IN1.1, U$7.9
INP11: IC_IN1.6, U$6.8
INP12: IC_IN1.2, U$7.8
IRQ: U3.P$4, U$4.6
IRQ1: U7.P$4, U$8.6
LED: LED.1, U3.P$10
LED1: LED1.1, U7.P$10
MEMORY_CS: U1.1, U3.P$15
MEMORY_CS1: U7.P$15, U8.1
MISO: IC_IN.9, SPI.3, U1.2, U3.P$13, U$2.13
MISO1: IC_IN1.9, SPI1.3, U7.P$13, U8.2, U$5.13
MOSI: IC_OUT.14, SPI.1, U1.5, U3.P$12, U$2.14
MOSI1: IC_OUT1.14, SPI1.1, U7.P$12, U8.5, U$5.14
unnamed: LED.2, R2.2
unnamed: LED_SYS.1, R5.2
unnamed: D1.C, PIEZO.1, R6.2
unnamed: ANT2.1, ANT3.1, U$5.10
unnamed: LED1.2, R8.2
unnamed: LED_SYS1.1, R11.2
unnamed: D2.C, PIEZO1.1, R12.2
unnamed: ANT.1, ANT1.1, U$2.10
OUT1: IC_OUT1.1, U$7.6
OUT2: IC_OUT.1, U$3.6
OUT3: IC_OUT.2, U$3.5
OUT4: IC_OUT.3, U$3.4
OUT5: IC_OUT1.2, U$7.5
OUT6: IC_OUT.5, U$1.4
OUT7: IC_OUT.6, U$1.5
OUT8: IC_OUT.7, U$1.6
OUT9: IC_OUT1.3, U$7.4
OUT10: IC_OUT1.5, U$6.4
OUT11: IC_OUT1.7, U$6.6
OUT12: IC_OUT1.6, U$6.5
PIEZO: R6.1, U3.P$11
PIEZO1: R12.1, U7.P$11
PWM1: U3.P$6, U$4.5
PWM2: U3.P$7, U$4.4
PWM3: U7.P$7, U$8.4
PWM4: U7.P$6, U$8.5
RADIO_CS: U3.P$16, U$2.15
RADIO_CS1: U7.P$16, U$5.15
RADIO_IRQ: U3.P$3, U$2.2
RADIO_IRQ1: U7.P$3, U$5.2
SCK: IC_IN.11, IC_OUT.11, SPI.2, U1.6, U3.P$14, U$2.12
SCK1: IC_IN1.11, IC_OUT1.11, SPI1.2, U7.P$14, U8.6, U$5.12
SCL: I2C.2, U3.P$24, U$4.9
SCL1: I2C1.2, U7.P$24, U$8.9
SDA: I2C.1, U3.P$23, U$4.8
SDA1: I2C1.1, U7.P$23, U$8.8
SHIFT_CS: IC_IN.10, IC_OUT.12, U3.P$8
SHIFT_CS1: IC_IN1.10, IC_OUT1.12, U7.P$8
SHIFT_IN_LOAD: IC_IN.12, IC_IN.13, U3.P$9
SHIFT_IN_LOAD1: IC_IN1.12, IC_IN1.13, U7.P$9
SHIFT_OUT_ENABLE: IC_OUT.13, R4.2, U3.P$5
SHIFT_OUT_ENABLE1: IC_OUT1.13, R10.2, U7.P$5
SWITCH: R1.2, SWITCH.1, U3.P$26
SWITCH1: R9.2, SWITCH1.1, U7.P$26

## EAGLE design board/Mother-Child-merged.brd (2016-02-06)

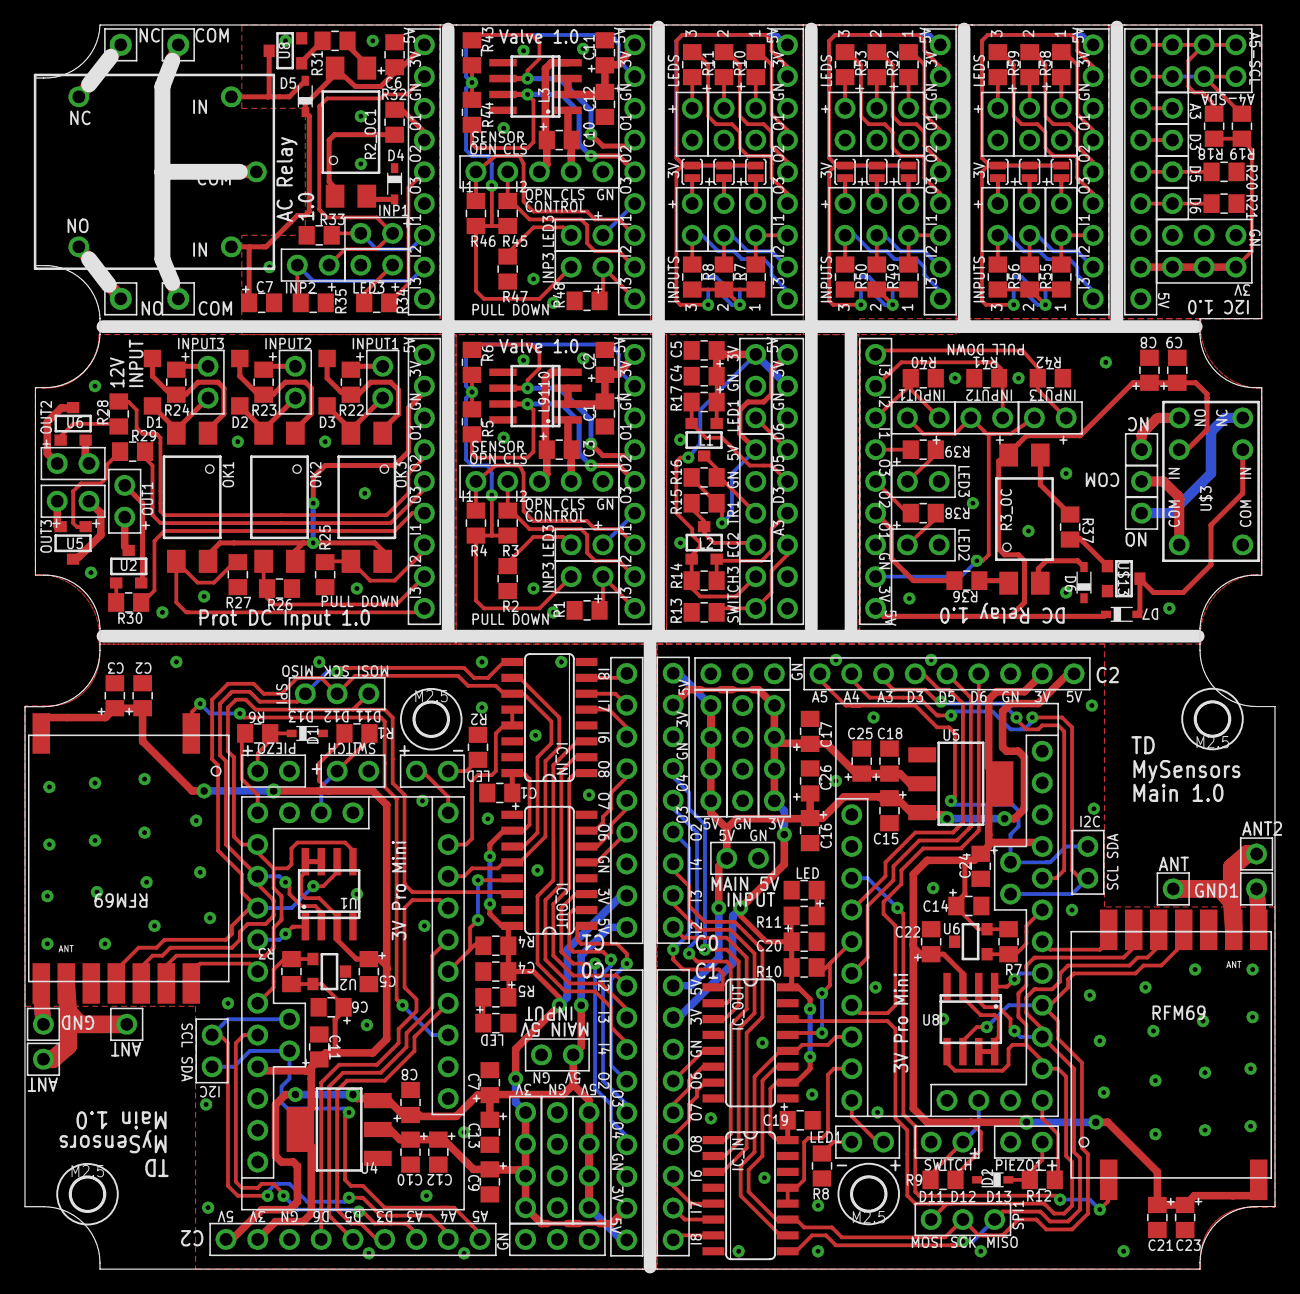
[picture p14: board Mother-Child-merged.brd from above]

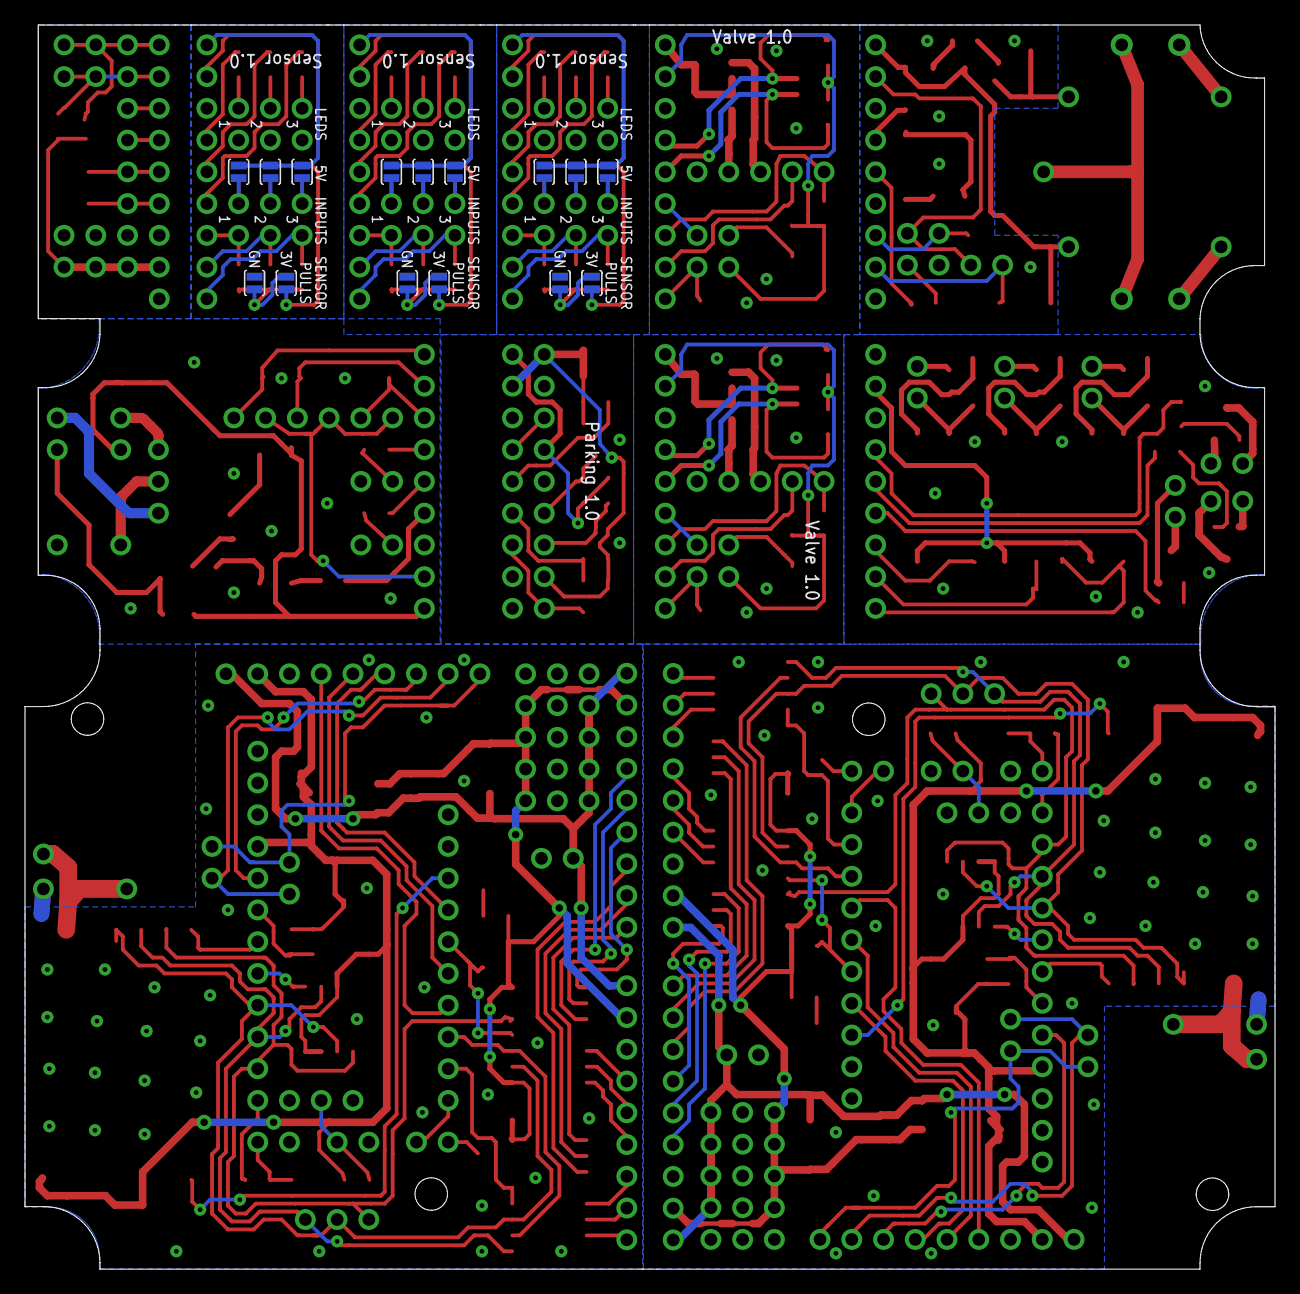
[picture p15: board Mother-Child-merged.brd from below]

Board: 4 copper layers, 100.0 x 99.5 mm, 278 parts (15 on the bottom side), 226 nets.

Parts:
ANT, ANT1, ANT2, ANT3: DUPONT_1
C1, C3, C4, C5, C6, C8, C10, C14, C15, C18, C19, C20, C22, C23, C31, C51, C71, C91, C101, C110, C121: 0.1uF; CAP_0805
C2, C7, C9, C11, C12, C13, C16, C17, C21, C24, C25, C26, C27, C41, C61, C81, C111: 10uF; CAP_0805
D1, D2, D4, D5, D6, D7: SOD323
D3, D11, D21: 1N4148; SOD123
GND, GND1: DUPONT_1
H1, H2, H3, H4: HOLE_MOUNTING_M2.5_TIGHT; HOLE_M2.5PAN_TIGHT
I2C, I2C1: DUPONT_2
IC_IN, IC_IN1: SO16
IC_OUT, IC_OUT1: SO16
J3V1, J3V2, J5V, J5V1: DUPONT_4
JGN1, JGN4: DUPONT_4
JGN2, JGN3: DUPONT_3
JINP, JINP1: DUPONT_2
L1, L2: SOT23-3
L3, L9110: L9110 Motor 1; SO-08
LED, LED1: DUPONT_2
LED_SYS, LED_SYS1: LED_0805
OK1, OK2, OK3: SO-4_PC817
PIEZO, PIEZO1: DUPONT_2
PINP1, PINP2, PINP3: DUPONT_2
PRK_DIST: DUPONT_4
PRK_LED: DUPONT_3
PSWITCH: DUPONT_2
R1, R4, R9, R10, R13, R14, R15, R16, R17, R20, R25, R26, R27, R31, R33, R35, R40, R41, R42, R43, R44, R45, R46, R48, R49, R50, R51, R55, R56, R57, R61, R71, R81, R91, R110, R211, R411, R511: 10K; R_0805
R2, R5, R8, R11, R21, R28, R29, R30, R32, R34, R36, R37, R38, R39, R47, R52, R53, R54, R58, R59, R60, R101, R111, R121, R311: 1K; R_0805
R2_LED, R2_SW, R2_SW1, R3_LED, R3_LED1: DUPONT_2
R2_OC1, R3_OC: SO-4_PC817
R2_RELAY: RELAY_SRD_SL_C; RELAY_SRD-SL-C
R3, R7, R22, R23, R24: 4.7K; R_0805
R6, R12: 220; R_0805
R18, R19: 4K7; R_0805
RELAY4, RELAY5, RELAY6: DUPONT_2
RINP4, RINP5, RINP6: DUPONT_2
SENLED1, SENLED2, SENLED3, SENLED4, SENLED5, SENLED6, SENLED7, SENLED8, SENLED9: DUPONT_2
SENSOR1, SENSOR2, SENSOR3, SENSOR4, SENSOR5, SENSOR6, SENSOR7, SENSOR8, SENSOR9, SENSOR10, SENSOR11, SENSOR12, SENSOR13, SENSOR14: DUPONT_2
SJ1, SJ2, SJ3, SJ4, SJ5, SJ6, SJ7, SJ8, SJ9, SJ10, SJ11, SJ12, SJ13, SJ14, SJ15, SJ16, SJ17, SJ18, SJ19, SJ20, SJ21, SJ22, SJ23, SJ24: PAD-JUMPER-2-NO_YES_SILK
SPI, SPI1: DUPONT_3
SWITCH, SWITCH1: DUPONT_2
U1, U8: SO-08
U2, U6, U21, U51, U61: SOT23-3
U3, U7: PRO_MINI_CLONE
U4, U5: AMS1117; SOT223
U$1, U$3, U$6, U$7: DUPONT_MALE90_9
U$2, U$5: RADIO_RFM69W_MS; RFM69W_MS
U$4, U$8, U$41: DUPONT_9
U$9, U$10, U$12, U$111: DUPONT_1_LRG
U$11, U$14, U$18, U$21, U$25, U$26, U$51, U$61, U$71: DUPONT_FEM90_9
U$13, U$81: SOT23-3
U$15, U$16, U$17, U$19, U$20, U$22, U$211: DUPONT_1
U$23, U$24: DUPONT_3
U$31: RELAY_G5V1; RELAY-G5V
VALVE, VALVE1: DUPONT_5
VLV_LED, VLV_LED1: DUPONT_2

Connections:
+3V1: C14.1, C17.1, C18.1, C19.1, C20.1, C21.1, C22.1, C23.1, C24.1, C25.1, IC_IN1.16, IC_OUT1.10, IC_OUT1.16, J3V2.1, J3V2.2, J3V2.3, J3V2.4, R7.2, R9.1, R10.1, R11.1, U5.2, U5.4, U6.2, U7.P$19, U8.3, U8.7, U8.8, U$5.8, U$6.2, U$7.2, U$8.2
+3V3: C1.1, C2.1, C3.1, C4.1, C5.1, C6.1, C9.1, C10.1, C11.1, C12.1, IC_IN.16, IC_OUT.10, IC_OUT.16, J3V1.1, J3V1.2, J3V1.3, J3V1.4, R1.1, R3.2, R4.1, R5.1, U1.3, U1.7, U1.8, U2.2, U3.P$19, U4.2, U4.4, U$1.2, U$2.8, U$3.2, U$4.2
+5V: C7.1, C8.1, C13.1, J5V.1, J5V.2, J5V.3, J5V.4, JINP.1, U4.3, U$1.1, U$3.1, U$4.1
+5V1: C15.1, C16.1, C26.1, J5V1.1, J5V1.2, J5V1.3, J5V1.4, JINP1.1, U5.3, U$6.1, U$7.1, U$8.1
ANALOG1: U7.P$18, U$8.7
ANALOG3: U3.P$18, U$4.7
CRYPT: R3.1, U2.1, U3.P$17
CRYPT1: R7.1, U6.1, U7.P$17
GND: C1.2, C2.2, C3.2, C4.2, C5.2, C6.2, C7.2, C8.2, C9.2, C10.2, C11.2, C12.2, C13.2, D1.A, GND.1, IC_IN.4, IC_IN.8, IC_IN.14, IC_IN.15, IC_OUT.8, JGN1.1, JGN1.2, JGN1.3, JGN1.4, JGN2.1, JGN2.2, JGN2.3, JINP.2, LED_SYS.2, PIEZO.2, R2.1, SWITCH.2, U1.4, U2.3, U3.P$2, U3.P$21, U3.P$27, U4.1, U$1.3, U$2.9, U$2.11, U$3.3, U$4.3
GND1: C14.2, C15.2, C16.2, C17.2, C18.2, C19.2, C20.2, C21.2, C22.2, C23.2, C24.2, C25.2, C26.2, D2.A, GND1.1, IC_IN1.4, IC_IN1.8, IC_IN1.14, IC_IN1.15, IC_OUT1.8, JGN3.1, JGN3.2, JGN3.3, JGN4.1, JGN4.2, JGN4.3, JGN4.4, JINP1.2, LED_SYS1.2, PIEZO1.2, R8.1, SWITCH1.2, U5.1, U6.3, U7.P$2, U7.P$21, U7.P$27, U8.4, U$5.9, U$5.11, U$6.3, U$7.3, U$8.3
I2C_+3V3: R18.1, R19.1, U$18.8, U$24.1, U$24.2, U$24.3
I2C_A3: U$18.3, U$19.1
I2C_D3: U$18.4, U$22.1
I2C_D5: R20.1, U$18.5, U$211.1
I2C_D6: R211.1, U$18.6, U$20.1
I2C_GND: R20.2, R211.2, U$18.7, U$23.1, U$23.2, U$23.3
I2C_SCL: R18.2, SENSOR4.2, SENSOR7.2, SENSOR8.2, U$18.1
I2C_SDA: R19.2, SENSOR4.1, SENSOR7.1, SENSOR8.1, U$18.2
INP1: IC_IN1.5, U$6.7
INP2: IC_IN.1, U$3.9
INP3: IC_IN.2, U$3.8
INP4: IC_IN.3, U$3.7
INP5: IC_IN1.7, U$6.9
INP6: IC_IN.5, U$1.7
INP7: IC_IN.6, U$1.8
INP8: IC_IN.7, U$1.9
INP9: IC_IN1.3, U$7.7
INP10: IC_IN1.1, U$7.9
INP11: IC_IN1.6, U$6.8
INP12: IC_IN1.2, U$7.8
IRQ: U3.P$4, U$4.6
IRQ1: U7.P$4, U$8.6
LED: LED.1, U3.P$10
LED1: LED1.1, U7.P$10
MEMORY_CS: U1.1, U3.P$15
MEMORY_CS1: U7.P$15, U8.1
MISO: IC_IN.9, SPI.3, U1.2, U3.P$13, U$2.13
MISO1: IC_IN1.9, SPI1.3, U7.P$13, U8.2, U$5.13
MOSI: IC_OUT.14, SPI.1, U1.5, U3.P$12, U$2.14
MOSI1: IC_OUT1.14, SPI1.1, U7.P$12, U8.5, U$5.14
unnamed: LED.2, R2.2
unnamed: LED_SYS.1, R5.2
unnamed: D1.C, PIEZO.1, R6.2
unnamed: ANT2.1, ANT3.1, U$5.10
unnamed: LED1.2, R8.2
unnamed: LED_SYS1.1, R11.2
unnamed: D2.C, PIEZO1.1, R12.2
unnamed: PINP1.2, R24.2
unnamed: D21.C, OK2.1, R23.1
unnamed: D21.A, OK2.2, PINP2.1
unnamed: ANT.1, ANT1.1, U$2.10
unnamed: C101.1, L3.4, VALVE1.3
unnamed: D3.C, OK3.1, R22.1
unnamed: D3.A, OK3.2, PINP3.1
unnamed: PINP3.2, R22.2
unnamed: R101.2, SENLED1.1
unnamed: R111.2, SENLED2.1
unnamed: R121.2, SENLED3.1
unnamed: R30.2, U21.1
unnamed: R52.2, SENLED4.1
unnamed: RELAY4.1, U21.3
unnamed: RELAY4.2, U21.2
unnamed: C101.2, L3.1, VALVE1.2
unnamed: R54.2, SENLED6.1
unnamed: SENSOR11.2, SJ13.1, SJ14.1
unnamed: SENSOR3.2, SJ5.1, SJ6.1
unnamed: SENSOR2.2, SJ3.1, SJ4.1
unnamed: R29.2, U51.1
unnamed: R28.2, U61.1
unnamed: R3_LED1.1, R39.1
unnamed: C31.1, L9110.4, VALVE.3
unnamed: RELAY5.2, U51.2
unnamed: RELAY6.1, U61.3
unnamed: RELAY6.2, U61.2
unnamed: R2_LED.1, R34.1
unnamed: D5.A, R2_RELAY.2, U$81.3
unnamed: R311.2, U$81.1
unnamed: R2_OC1.3, R311.1
unnamed: D4.A, R2_OC1.2
unnamed: R2_OC1.1, R32.1
unnamed: C31.2, L9110.1, VALVE.2
unnamed: R37.2, U$13.1
unnamed: R3_OC.3, R37.1
unnamed: D6.A, R3_OC.2
unnamed: R3_OC.1, R36.1
unnamed: R3_LED.1, R38.1
unnamed: U$16.1, U$31.5
unnamed: SENSOR1.2, SJ1.1, SJ2.1
unnamed: SENSOR10.2, SJ11.1, SJ12.1
unnamed: SENSOR9.2, SJ9.1, SJ10.1
unnamed: R21.1, VLV_LED.2
unnamed: R59.2, SENLED8.1
unnamed: R60.2, SENLED9.1
unnamed: SENSOR14.2, SJ21.1, SJ22.1
unnamed: SENSOR13.2, SJ19.1, SJ20.1
unnamed: SENSOR12.2, SJ17.1, SJ18.1
unnamed: D11.C, OK1.1, R24.1
unnamed: D11.A, OK1.2, PINP1.1
unnamed: PINP2.2, R23.2
unnamed: R47.1, VLV_LED1.2
unnamed: R53.2, SENLED5.1
unnamed: RELAY5.1, U51.3
unnamed: D7.A, U$13.3, U$31.9
unnamed: R58.2, SENLED7.1
OUT1: IC_OUT1.1, U$7.6
OUT2: IC_OUT.1, U$3.6
OUT3: IC_OUT.2, U$3.5
OUT4: IC_OUT.3, U$3.4
OUT5: IC_OUT1.2, U$7.5
OUT6: IC_OUT.5, U$1.4
OUT7: IC_OUT.6, U$1.5
OUT8: IC_OUT.7, U$1.6
OUT9: IC_OUT1.3, U$7.4
OUT10: IC_OUT1.5, U$6.4
OUT11: IC_OUT1.7, U$6.6
OUT12: IC_OUT1.6, U$6.5
PARK_+3V3: C41.1, C51.1, L1.1, L2.1, PRK_LED.1, PSWITCH.2, R14.2, R17.2, U$41.8
PARK_+5V: PRK_DIST.1, R15.2, R16.2, U$41.9
PARK_ECHO: L2.2, R14.1, U$41.4
PARK_ECHO_5V: L2.3, PRK_DIST.4, R15.1
PARK_GND: C41.2, C51.2, PRK_DIST.2, PRK_LED.2, R13.2, U$41.7
PARK_RING: PRK_LED.3, U$41.6
PARK_SWITCH: PSWITCH.1, R13.1, U$41.3
PARK_TRIGGER: L1.2, R17.1, U$41.5
PARK_TRIGGER_5V: L1.3, PRK_DIST.3, R16.1
PIEZO: R6.1, U3.P$11
PIEZO1: R12.1, U7.P$11
PROT_+3V3: OK1.4, OK2.4, OK3.4, U$11.8
PROT_GND: R25.1, R26.1, R27.1, U$11.7
PROT_INPUT1: OK1.3, R27.2, U$11.1
PROT_INPUT2: OK2.3, R26.2, U$11.2
PROT_INPUT3: OK3.3, R25.2, U$11.3
PROT_RELAY1: R30.1, U$11.4
PROT_RELAY2: R29.1, U$11.5
PROT_RELAY3: R28.1, U$11.6
PWM1: U3.P$6, U$4.5
PWM2: U3.P$7, U$4.4
PWM3: U7.P$7, U$8.4
PWM4: U7.P$6, U$8.5
R2_COM: R2_RELAY.3, U$10.1, U$12.1
R2_NC: R2_RELAY.5, U$111.1
R2_NC1: U$17.1, U$31.1
R2_NO: R2_RELAY.4, U$9.1
R2_NO1: U$15.1, U$31.10
RADIO_CS: U3.P$16, U$2.15
RADIO_CS1: U7.P$16, U$5.15
RADIO_IRQ: U3.P$3, U$2.2
RADIO_IRQ1: U7.P$3, U$5.2
REL_AC_+3V3: R2_SW.2, R2_SW1.2, U$71.8
REL_AC_+5V: C61.1, C71.1, D5.C, R2_OC1.4, R2_RELAY.1, U$71.9
REL_AC_GND: C61.2, C71.2, D4.C, R2_LED.2, R33.2, R35.2, U$71.7, U$81.2
REL_AC_INP1: R2_SW1.1, R33.1, U$71.3
REL_AC_INP2: R2_SW.1, R35.1, U$71.2
REL_AC_LED2: R34.2, U$71.5
REL_AC_RELAY: R32.2, U$71.6
REL_DC_+3V3: RINP4.2, RINP5.2, RINP6.2, U$14.8
REL_DC_+5V: C81.1, C91.1, D7.C, R3_OC.4, U$14.9, U$31.2
REL_DC_CTRL1: R36.2, U$14.6
REL_DC_GND: C81.2, C91.2, D6.C, R3_LED.2, R3_LED1.2, R40.2, R42.2, R411.2, U$13.2, U$14.7
REL_DC_INP1: R40.1, RINP4.1, U$14.3
REL_DC_INP2: R411.1, RINP5.1, U$14.2
REL_DC_INP3: R42.1, RINP6.1, U$14.1
REL_DC_LED2: R38.2, U$14.5
REL_DC_LED3: R39.2, U$14.4
SCK: IC_IN.11, IC_OUT.11, SPI.2, U1.6, U3.P$14, U$2.12
SCK1: IC_IN1.11, IC_OUT1.11, SPI1.2, U7.P$14, U8.6, U$5.12
SCL: I2C.2, U3.P$24, U$4.9
SCL1: I2C1.2, U7.P$24, U$8.9
SDA: I2C.1, U3.P$23, U$4.8
SDA1: I2C1.1, U7.P$23, U$8.8
SENSOR_1: R71.1, SENSOR1.1, U$61.3
SENSOR_2: R81.1, SENSOR2.1, U$61.2
SENSOR_3: R91.1, SENSOR3.1, U$61.1
SENSOR_4: R49.1, SENSOR9.1, U$25.3
SENSOR_5: R50.1, SENSOR10.1, U$25.2
SENSOR_6: R511.1, SENSOR11.1, U$25.1
SENSOR_7: R55.1, SENSOR12.1, U$26.3
SENSOR_8: R56.1, SENSOR13.1, U$26.2
SENSOR_9: R57.1, SENSOR14.1, U$26.1
SENSOR_+3V1: SJ9.2, SJ11.2, SJ13.2, SJ15.2, U$25.8
SENSOR_+3V2: SJ17.2, SJ19.2, SJ21.2, SJ23.2, U$26.8
SENSOR_+3V3: SJ1.2, SJ3.2, SJ5.2, SJ7.2, U$61.8
SENSOR_+5V: SJ2.2, SJ4.2, SJ6.2, U$61.9
SENSOR_+5V1: SJ10.2, SJ12.2, SJ14.2, U$25.9
SENSOR_+5V2: SJ18.2, SJ20.2, SJ22.2, U$26.9
SENSOR_GND: SENLED1.2, SENLED2.2, SENLED3.2, SJ8.2, U$61.7
SENSOR_GND1: SENLED4.2, SENLED5.2, SENLED6.2, SJ16.2, U$25.7
SENSOR_GND2: SENLED7.2, SENLED8.2, SENLED9.2, SJ24.2, U$26.7
SENSOR_LED1: R101.1, U$61.6
SENSOR_LED2: R111.1, U$61.5
SENSOR_LED3: R121.1, U$61.4
SENSOR_LED4: R53.1, U$25.5
SENSOR_LED5: R52.1, U$25.6
SENSOR_LED6: R54.1, U$25.4
SENSOR_LED7: R59.1, U$26.5
SENSOR_LED8: R58.1, U$26.6
SENSOR_LED9: R60.1, U$26.4
SENSOR_PULL: R71.2, R81.2, R91.2, SJ7.1, SJ8.1
SENSOR_PULL1: R49.2, R50.2, R511.2, SJ15.1, SJ16.1
SENSOR_PULL2: R55.2, R56.2, R57.2, SJ23.1, SJ24.1
SHIFT_CS: IC_IN.10, IC_OUT.12, U3.P$8
SHIFT_CS1: IC_IN1.10, IC_OUT1.12, U7.P$8
SHIFT_IN_LOAD: IC_IN.12, IC_IN.13, U3.P$9
SHIFT_IN_LOAD1: IC_IN1.12, IC_IN1.13, U7.P$9
SHIFT_OUT_ENABLE: IC_OUT.13, R4.2, U3.P$5
SHIFT_OUT_ENABLE1: IC_OUT1.13, R10.2, U7.P$5
SWITCH: R1.2, SWITCH.1, U3.P$26
SWITCH1: R9.2, SWITCH1.1, U7.P$26
VALVE_+3V1: R43.1, R44.1, R45.1, R46.1, SENSOR6.2, U$51.8
VALVE_+3V3: R31.1, R41.1, R51.1, R61.1, SENSOR5.2, U$21.8
VALVE_+5V: C27.1, C110.1, L9110.2, L9110.3, U$21.9
VALVE_+5V1: C111.1, C121.1, L3.2, L3.3, U$51.9
VALVE_CLOSED: R31.2, U$21.2, VALVE.4
VALVE_CLOSED1: R45.2, U$51.2, VALVE1.4
VALVE_CONTROL1: L9110.6, R61.2, U$21.6
VALVE_CONTROL2: L9110.7, R51.2, U$21.5
VALVE_CONTROL3: L3.6, R43.2, U$51.6
VALVE_CONTROL4: L3.7, R44.2, U$51.5
VALVE_GND: C27.2, C110.2, L9110.5, L9110.8, R21.2, R110.2, U$21.7, VALVE.1
VALVE_GND1: C111.2, C121.2, L3.5, L3.8, R47.2, R48.2, U$51.7, VALVE1.1
VALVE_LED: U$21.4, VLV_LED.1
VALVE_LED1: U$51.4, VLV_LED1.1
VALVE_OPENED: R41.2, U$21.3, VALVE.5
VALVE_OPENED1: R46.2, U$51.3, VALVE1.5
VALVE_SENSOR1: R48.1, SENSOR6.1, U$51.1
VALVE_SENSOR3: R110.1, SENSOR5.1, U$21.1
